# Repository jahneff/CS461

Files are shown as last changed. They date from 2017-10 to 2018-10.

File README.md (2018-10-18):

# Capstone-GS2 (Green Smart Gardening System)
Respository for Green Smart Gardening System Project

**This is a capstone project contracted by Intel and delivered by Jiayu Han, Brandon Ellis, and Jack Neff of Oregon State University. The finished product is a RESTful web app connected to an IOT environmental sensor array, designed to help farmers record and monitor environmental conditions on their land.**

Authors: Jiayu Han, Brandon Ellis, Jack Neff

Smart-Gardening-Capstone
This is the main repository for the 2017 capstone project: Green Smart Gardening System. Authors: Jack Neff, Brandon Ellis, Jiayu Han

The Green Smart Gardening System

Client: Po-Cheng Chen Affiliation: Intel

Motivation: 
The health of lawn and garden is strongly related to the environment factors (e.g. temperature, humility, and soil moisture). In order to have a better control and understanding on the environmental requirements for different plants, a smart garden system that can monitor, extract and control multiple environment parameters will help people reduce maintenance efforts and grow better plants more efficiently.

Description: 
Smart home gardening has become more popular these years. Throughout this project, students will develop a green energy powered Internet-of-Thing (IOT) device that monitors home environmental conditions by collecting real time crucial information under cloud database and further create an analytic model of the plants growing pattern. The Green Smart Gardening System will then interact with the existing smart house system (e.g. thermostat and sprinkler systems).

Objectives: 
Build a prototype of green energy (e.g. solar) powered IOT device focusing on the environmental condition monitoring. This project will enable students to learn how to interface with multiple sensors with a micro-controller and collect the analytic data through low-power wireless communication technology to the cloud data base.

Deliverables: 
A prototype of the smart gardening system with (1)	Basic environment monitoring capability (e.g. soil moisture, temperature, humility, and air condition, etc.) using green energy (2)	Transfer captured data into a computer for data analysis (3)	Transmit analyzed data into a phone or another device wirelessly (optional) (4)	Build data analytic model for plants health verse environment factors (optional)

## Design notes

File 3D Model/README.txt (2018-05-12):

This is the 3D model for packaging. 

The entire design was using Google Sketchup, and export as STL file for 3D printing.

Main, Mainlid:
	Most of sensors;
	MKR1000 with MKR stand;
	Breadboard.

MKR:
	MKR1000 stand.

SoilLeft, SoilRight:
	Soil Moisture sensor.

Solar, Solarlid:
	Solar panel;
	Battery;
	Light sensor.

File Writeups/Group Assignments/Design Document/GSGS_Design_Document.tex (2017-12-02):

\documentclass[IEEEtran,letterpaper,10pt,titlepage,fleqn,draftclsnofoot,onecolumn]{article}
%notitlepage vs titlepage
%fleqn left align

%\usepackage{nopageno} %no page numbers
\usepackage{indentfirst}
\usepackage{alltt}                                           
\usepackage{float}
\usepackage{color}
\usepackage{url}

\usepackage{graphicx}                                        
\usepackage{amssymb}                                         
\usepackage{amsmath}                                         
\usepackage{amsthm}                                          

\usepackage{balance}
%\usepackage[TABBOTCAP, tight]{subfigure}
\usepackage{enumitem}
\usepackage{pstricks, pst-node}
\usepackage{geometry}
\usepackage{hyperref}
\usepackage{textcomp}
\usepackage{listings}
%allows for code snipets

\geometry{textheight=9.5in, textwidth=7in} 

\newcommand{\cred}[1]{{\color{red}#1}} %think function call, changes text to red
\newcommand{\cblue}[1]{{\color{blue}#1}} %text to blue
\definecolor{dkgreen}{rgb}{0,0.6,0}
\definecolor{gray}{rgb}{0.5,0.5,0.5}
\definecolor{mauve}{rgb}{0.58,0,0.82}
\lstset{frame=tb,
  language=c,
  aboveskip=3mm,
  belowskip=3mm,
  showstringspaces=false,
  columns=flexible,
  basicstyle={\small\ttfamily},
  numbers=none,
  numberstyle=\tiny\color{gray},
  keywordstyle=\color{blue},
  commentstyle=\color{dkgreen},
  stringstyle=\color{mauve},
  breaklines=true,
  breakatwhitespace=true,
  tabsize=3
}

\def\name{Brandon Ellis, Jiayu Han, and Jack Neff}
\def\class{CS 461}
\def\assignment{Design Document}

%PDF Properties
\hypersetup{
  colorlinks = true,
  urlcolor = black,
  pdfauthor = {\name},
  pdfkeywords = {CS461 Senior Capstone Design Document},
  pdftitle = {\class \assignment},
  pdfsubject = {\class \assignment},
  pdfpagemode = UseNone
}

\begin{document}
%TitlePage
\begin{titlepage}
  \begin{center}
    \vspace{1cm}
    
    \huge
    \textbf{Green Smart Gardening System: Design Document}
    
    \vspace{1.5cm}
    
    \large
        \textbf{Brandon Ellis, Jiayu Han, and Jack Neff}
    
    \vspace{5cm}
    
    Abstract
    
    \normalsize
    This document discusses some core components that will make up our final product, a solar powered gardening device that provides the user with environmental data. There are three key pieces of functionality that this document will cover: Soil Moisture, Air Temperature \& Humidity, and Microcontrollers. The first two of these relate to environmental sensors that the chosen microcontroller will connect to. The last section covers the microcontroller itself. Each of these sections offer a description of the required task and go on to contrast different options to achieve these tasks.
    
    \vfill
    
    \large
        CS 461\\
        Fall Term\\
    \end{center}
\end{titlepage}

\section{Introduction}

This document will discuss core design aspects of our Green Smart Gardening System. It will detail nine different pieces of core functionality and note the member of our group assigned to it. The individual pieces will be discussed based on their hierarchy, which is shown in the section below. The pieces themselves are Soil Sensors, Air Sensors, Board Logic, Power, Wi-Fi, Database, Web Application, Displaying Data, and Packaging. 	These pieces will be discussed in terms of developing our device, a green energy powered garden monitoring system.

\section{Hierarchy}

\begin{figure}[H]
  \caption{Piece Hierarchy}
  \centering
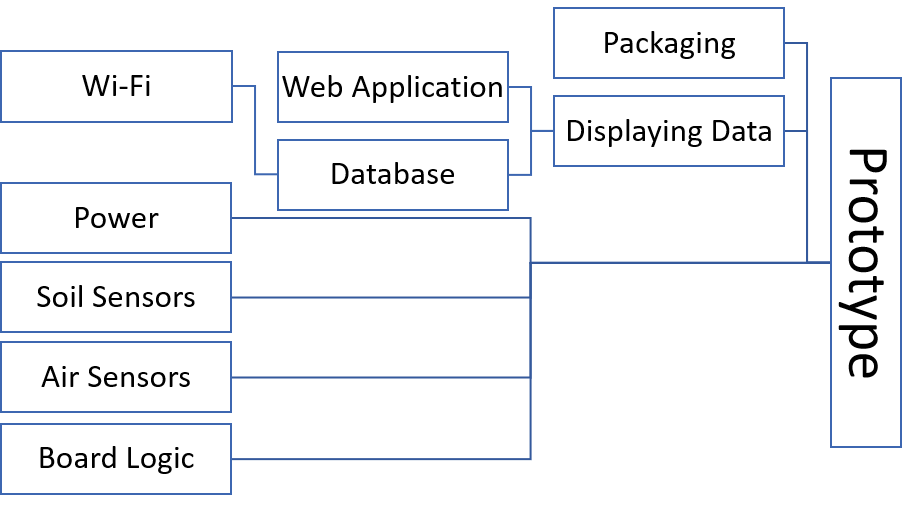
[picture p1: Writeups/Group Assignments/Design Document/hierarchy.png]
  
\end{figure}

\section{Design Pieces}
\subsection{Soil Sensors}
\subsubsection{Management: Brandon Ellis}

The first sensor related piece that will be covered is soil sensors. This section will cover two separate sensors, that together will achieve our devices soil requirements. These requirements being the measurement of soil moisture and soil pH. At this time, the two sensors that are being looked at to fill these roles are, respectively, the Phantom YoYo and the EZO pH Circuit. The process of integrating these sensors into our system will be the same for both. There will have to be a wired connection between each sensor and the board. There will need to be a software connection, so the board can easily communicate with the sensor. Finally, when this is all in place, the sensors will need to be tested.

\subsubsection{Hardware}

The first task in connecting the sensors to the board. For the YoYo, the required connections will be made through the sensor’s three pins: VCC, GND, and OUT. These three will support powering the YoYo and outputting measurements from it. Powering the sensor is fairly straightforward, with a wired connection simply needing to be made between the VCC and GND pins on the YoYo to their respective pins on the board. In order for the sensor to send information to the board, the last pin on the YoYo is used. The OUT pin is an analog output which can be connected to one of our board’s analog input pins. These three connections will be made through breadboard, in order to maximize the number of components our board can be interfaced with. 

\begin{figure}[H]
  \caption{YoYo Hookups}
  \centering
    \includegraphics[width=0.5\textwidth]
  {yoyo_hookup}
\end{figure}

For the EZO pH Circuit, there are some slight differences in connections. Power will still be handled in the same fashion as the YoYo, with the sensor’s VCC and GND connecting to the VCC and GND power pins of the microcontroller. The main difference between these two sensors is how output is handled. The EZO, instead of a single analog pin, uses two pins. These two pins are TX/SDA and RX/SCL. What this provides is two different connection modes, UART and I2C, working through these pins. Our board has options for both types, though I2C will most likely be used as it is more versatile when working with multiple components. The final hookup for the EZO is its replaceable sensor. This is the portion of the device that physically goes into the soil. It is connected through two pins on the EZO that link via a breadboard to the soil sensor’s screw-in connection point.
\begin{figure}[H]
  \caption{EZO Hookups}
  \centering
    \includegraphics[width=0.5\textwidth]
  {ezo_hookup}
\end{figure}

\subsubsection{Software}

Once the hardware connections to these two sensors have been made, the board needs to understand how to communicate with it. For the YoYo, using analog methods, this a simple matter of assigning the pin internally on the microcontroller and using the read command. The EZO on the other hand, because of its I2C communication mode, will require a little more work. In order to communicate with this sensor, the board will have to note its address and then perform reading operations on it in a slightly more expanded manner than using a single command. Sample code is provided for the EZO on exactly how to make this communication. 

\subsubsection{Testing}

When these two steps have been completed, a physical connection between the sensors and board has been made and data is able to be transferred to the microcontroller. When other pieces of our device have been implemented, specifically saving data to an SD card and wireless connectivity, testing can then be done. The actual testing of these sensors will be done through the Oregon State Greenhouses to compare against a reliable and accurate source. 

\subsection{Air Sensor}
\subsubsection{Management: Brandon Ellis}

The second large sensor piece that will be covered is air sensors. In order to fulfill the required functionality for our air sensor, we need to measure air temperature and humidity. The component chosen to fill this role is the SparkFun Atmospheric Sensor Breakout BME280. The BME280 not only measures both relative humidity and temperature, but also notes the barometric pressure. To integrate this sensor with our system there will need to be a wired connection between the device. This will then allow communication from the sensor to our board, which will in turn allow us to test the validity of our data.

\subsubsection{Hardware}

The first step in this process is the physical connection of the BME280 to our board. In order to connect the two, the sensor requires power and a method of communication. To facilitate power, the BME280 has two pins that will need to be wired to the board. These are VCC and GND, to respectively provide 3.3V of power and a ground line. When these have been connected, there are then two forms of communication that the BME280 can utilize. In the above section, the EZO pH Circuit had two communication methods sent over the same pins. The BME280 differs by having two completely separate buses that each have their own method of communication, I2C and SPI. Though, like the EZO, the method of communication that we will be using is I2C, as it is the best method when working with multiple components connecting to a board. Connecting through I2C will entail connecting two pins, SDA and SCL, to their respective pins on our microcontroller.

\begin{figure}[H]
  \caption{BME280 Hookups}
  \centering
    \includegraphics[width=0.5\textwidth]
  {bme280_hookup}
\end{figure}

\subsubsection{Software}

When first step is complete, a hardware connection has been created to our sensor. The microcontroller then needs to have software created to communicate with the sensor and retrieve data from it. Because of the method of communication being through I2C, the implementation of software for the BME280 will require noting the I2C address and dictating operations for the sensor. To do this, the BME280 provides several pieces of sample code and example configurations.

\subsubsection{Testing}

Finally, when the hardware and software connections have been created data can be outputted from the sensor to the board. At this time, assuming that functionality is in place to further output data wirelessly or to a SD card, testing can begin. Like the above soil sensors, testing will be done with the Oregon State Greenhouses in order to test the accuracy of our data points against theirs. 

\subsection{Power}
\subsubsection{Management: Jiayu Han}

For the power source section, there are some criteria we need to follow. First, Green Smart Gardening System needs to use renewable energy as the primary power source, it is supposed to use solar power as much as possible. Second, the device is supposed to run without any solar power for an entire week since Oregon rains so often during November to March. It will be hard to fully rely on the solar power during the wet season in Oregon. 

To reach the first criterion, the device needs to be powered by the solar power for most of the time. The micro-controller, Arduino MKR1000, has a great feature to achieve it. According to Arduino website [1], MKR1000 has two battery connectors, the USB power source and the Vin. The USB power source will be disconnected if there is appropriate power detected through Vin. The board has a 5V power supply voltage and a 3.3V operating voltage. By plugging the 5V solar panel through the Vin and the 3.7V Li-ION batteries through the USB, the board will always use the solar panel as the power source when it is available.  Based on the reviews on SparkFun [2], the solar panel will become undetectable once the voltage drops below 3.3V, and the Li-ION batteries will kick in from that.

\begin{figure}[H]
  \caption{MKR1000 Power[3]}
  \centering
    \includegraphics[width=0.5\textwidth]
  {power_graphic_1}
\end{figure}

As a backup plan for the power source, the solar module for Arduino [5] is also a great solution. It combines the solar panel and rechargeable batteries into one power source for the Arduino board. The module can handle two different inputs. The 3.7V to 7.0V one will be able to charge the battery, and the 3.7V to 6.0V one will be able to carry out the charge from the USB. Both solar panel and batteries are easy to change to the specific ones fit the device.

\begin{figure}[H]
  \caption{Solar Module[5]}
  \centering
    \includegraphics[width=0.5\textwidth]
  {power_graphic_2}
\end{figure}

To achieve the second criterion, the battery capacity needs to be at least 34000mAh. According to Arduino, the Wi-Fi module on MKR1000 absorbs roughly 100mA when connected to Wi-Fi with data transferring. The board consumption without Wi-Fi module initialized is 20mA. Based on the specs from the Technology Review document for the project, the preferred air temperature and humidity sensor and soil moisture sensor have a total of 21mA. Based on the equation from Arduino website, Battery Life = (Battery Capacity)/ (Maximum Current Consumption) * 0.7, we can get the equation for battery capacity, Battery Capacity = (Battery Life) *(Maximum Current Consumption)/0.7, which the battery capacity = (7*24h) * (141mA)/ 0.7 = 33840mAh.

\subsection{Wi-Fi}
\subsubsection{Management: Jiayu Han}

One of the biggest benefits of choosing Arduino MKR1000 as the micro-controller is that it comes with the ATSAMW25 Wi-Fi module on board, which makes it the ideal solution for designing IoT project. The on-board Wi-Fi module has up to 72Mbps with a great operating temperature range from -40°C to +85°C.

In order to get the Arduino MKR1000 connected to Wi-Fi, you will only need the MKR1000 with Arduino IDE. Before connecting the MKR1000 with the Wi-Fi, the MKR1000 needs to be already set up to connect to computer and able to upload custom sketch. After the MKR1000 is successfully connected, we will go to the Arduino WIFI 101 Shield repository on GitHub[6] to aquire the zipped Wi-Fi library. Then, we will open the Arduino IDE, find the “Include Library” in Sketch menu, and click “Add .ZIP Library” to add the repository. After these three steps, the MKR1000 is ready to connect to the Wi-Fi. We will need to include the WiFi101 library in the sketch and pick the Wi-Fi which it needs to connect to. 

\subsection{Board Logic}
\subsubsection{Management: Brandon Ellis}

Board logic handles the overarching software that will control and coordinate our device. While each of the sensors will have its own software associated with it, the purpose behind those pieces is heavily focused on communication and data retrieval. This section will detail some of the broad functionality that will be created as well as their associated testing.

The main pieces of functionality that will be discussed are data retrieval, outputting data, and scheduling. Out of these three, data retrieval is going to play the most off the software developed for each sensor. This piece of functionality will be responsible for querying those implemented functions and returning with the data. Once data has been retrieved, the data outputting portion will take over handling it. Retrieved data will be formatted and stored on an SD card. This will serve as a way to first back up the data. As our device is run off solar power and a battery, in the event of poor weather conditions for an extended period we need to be able to save the data in case transmitting would cause too much of a power draw. This way, when data is outputted it will be collected from the SD card to ensure it is backed up prior to transmission. The final piece of functionality that will be added is scheduling. Scheduling is the automated nature of our device to ensure that readings are taken in standard intervals. This addition will control when readings are taken from each sensor and when data this data will be transferred.  

Finally, this leaves how these pieces of functionality will be tested. There will be two main types of testing done on this software. The first will cover data retrieval and output, which is through unit testing. This will simply ensure that each of these individual pieces are operating correctly. The other type of testing that will be conducted is integration testing. This will be used to validate the scheduling portion, specifically this style of testing will aid in making sure that all of the individual pieces are able to work in tandem within our system.

\subsection{Database}
\subsubsection{Management: Jack Neff}

The storage and access of data is one of the most important aspects of our project, which is very data driven. Without the ability to consistently gather and store data, our application would be useless. This begs the question as to what database should we use, and what storage engine within that database? 

Database availability was the chief factor here. Each platform has a database software associated with it, so by selecting a platform one effectively is restricted to that platform’s database. We reasoned that users wouldn’t have much to do with the database. In fact, the less they have to do with it, the better. Therefore we picked our database solely based on our own needs and whether it met them. MySQL is one the three of us are all familiar with, and since it is supported by Google Cloud, we opted to go with it. [7]

We have more choices for the database storage engine. Our database has few outstanding requirements. Speed is not our top concern. Although we want to make sure our application is never sluggish, the nature of our application would allow us to voluntarily reduce data throughput in case of a slowdown, with minimal performance impact. For example, if we queried the database to graph environment data for a full year, we could leave out every other data point to reduce the workload by half, and still end up with a similar graph, provided our measurement interval is short enough. Additionally, In order to implement our preferred structure, foreign key support will be required, for cross-table references, as well as transaction support for data simplification possibly the computation of metrics. This led us to select InnoDB as our storage engine, because it supports foreign keys and transactions, is very fast, and we have all used it before. Also, InnoDB supports multi-view concurrency control (MVCC), which means we can all work on the database at the same time with no issues.[8]

A final design consideration regarding the database is what should be stored, and in what form? Our data will consist mostly of environmental measurements associated with a timestamp. For example, one database column could be Temp and another could be Time. This would allow us to graph the temperature over time. To simplify data analysis and display, we will design the input to come through in “packets.” We are measuring a lot of environmental factors (temperature, humidity, soil moisture, etc.), and if they each had their own timestamp, things would get very messy. Therefore, we want these packets to hold one measurement of each environmental variable, coupled with a timestamp that corresponds to all those measurements. These packets will be easily graphed and will be highly comparable because of their common timestamps, which will make generating views easier.

\subsection{Web Application}
\subsubsection{Management: Jack Neff}

Server stack implementation is an important software design decision for us. We refer to this design aspect as the server platform. The question is, what platform should we select to store and maintain our application and all its data? Users will be dependent on this platform to support their data needs, and to form the operational infrastructure of the Gardening System. Primarily we want to direct this design based on scalability and reliability, with a secondary concern for ease of use by the user. 

One design decision involving the server stack is what operating system we want it to be usable on. Several popular server platform stacks such as WAMP are windows only, while others are specifically designed for Linux, and still others work with any OS. In the interest of reaching the largest possibly client base, we wanted to use a server stack that was supported on all operating systems. This is one of the design points that led us to select Google Cloud Platform as our web server: it isn’t platform specific.

Another factor is scalability. As a group we have experience of hosting http servers on a local virtual machine, only to have performance suffer when data operation and data storage volumes became too large for it to handle. The Google Cloud Platform is supported on hearty and fast infrastructure, the same which supports google searches, or playback of YouTube videos. It is a tried and true resource capable of handling lots of computing, which we may need if we ever adapt our design full scale. Our prototype will be a small system consisting of one of a few plants, but the large scale implementation of a vineyard or orchard (or multiple) would significantly increase data throughput and calculations done in analysis. 

One fairly obvious design choice was what language to use to implement the web application. The language needs to be able to interface between database and web browser, and should preferable be simple, and a language we the developers are already familiar with. We selected PHP because it is supported by all server platforms, and is known for being one of the easiest if not the easiest language for accessing databases. It also helps that all three of us have experience programming in PHP, and querying databases in PHP. 

Other, lesser factors included reliability and ease of use by the developers. Reliability is not an emphasis here simply because most server platform stacks are pretty reliable. Google Cloud Platform though, especially, is known to be very reliable, since it is based on Google’s famous infrastructure. Ease of use was a concern entirely our own, and is important because selecting an easy-to-use application saves time and effort that could have been spent debugging or learning to use the software. Known for being easy to use and for having a large body of community support online, the Cloud Platform satisfies this requirement well. 

\subsection{Displaying Data}
\subsubsection{Management: Jack Neff}

Data display is the key to bringing information to the user in a way that is easy to understand and can inform their agricultural decisions. Data displays should be easy to understand, and be viewable on the web-based user interface. Users should be able to easily construct their own graphs based on available data. In addition, some graphs should be automatically generated from data in the database. This part of our design is completely geared toward the user. We want to make the data we collect very understandable, even by someone without a lot of math, computer, or agricultural experience. Also, we want to give the user relevant information, rather than just bombarding them with numbers and timestamps. Finally, we want the data to look good, and dynamically create graphs and views without causing any slowdown.

To fulfill cosmetic requirements, we selected D3js as our API for data display. This is a JavaScript library that provides lots interesting data display functionality. In addition, because it is a JavaScript library and not a program itself, we expect it will be fast and lightweight. [9]

When the user logs into the web application, they should have the most valuable information distilled for them on the main page. Although at first in our design we flirted with trying to implement low-level machine learning, we have now realized there won’t be enough time, so we will be doing independent research into plant growth to find out what types of plants are healthy in what environments. Using these known benchmarks, we will provide users with information about their system’s environment, and how this information relates to the ideal environment conditions for a plant. An early design idea is to have a colored bar or a circle for each environmental variable plainly visible on the application front page. If the variable is within acceptable bounds, the graph element would be green, and red if not. By clicking on that element, a user could view a graph of that element by itself over time, and analyze why it is out of the required range.

One interesting design consideration is how much freedom to allow the user to have when graphing their own data. Because users of this product may not be very computer-savvy, the users’ ability to make their own graphs should be limited to a few preset options, to avoid presenting them with an overwhelming array of choices. Variables should be graphable against one another, as well as against time, and there should be a wide number of graphical options for each type of graph. D3js specializes in radial displays and maps, and since we won’t be needing maps, we will likely design a number of radial displays. Users should be able to save their graphs and mount them on the front page of the web app if they like. 

One of the keys to an enjoyable user experience is speed and responsiveness of an app. We want the user to see graphs as soon as they log in, but if these dynamic graphs hurt performance, that is unacceptable. We will implement some kind of contingency against this, so instance, if the application detects that the front page of the app is loading slowly, it should cut the number of data points in half by selecting every other one, and then reload the page. User experience needs to be the absolute focus of this design element. There is no utility in showing off data or graphs unless the user wants to view them and is not put off by long loading times.

\subsection{Packaging}
\subsubsection{Management: Jiayu Han}

Our vision of the device will be stored in a package. The micro-controller and the batteries along with most of the cables will be stored inside of the case in order to protect them from damaging. Outside of the package will only have the solar panel, the soil moisture sensor and the air temperature \& humidity sensor to collect the energy to power up the device and the data for analyzation. In order to make the device package firm with high pressure resistance, cylindrical package will be the best option. It will easily hold its shape to protect the device inside from sticking into the soil. The solar panel will be set at the top of the package so that it could produce solar power at its maximum efficient. The air temperature \& humidity sensor will extend from the top of the side so that the temperature and humidity will have a lower chance of appearing errors because of the ground temperature and humidity. The soil moisture sensor will come out from the bottom of the package in order to get to the similar depth as the root of the plants to collect more precise data.

Based on the purpose of the Green Smart Gardening System, the device needs to be used outdoor and waterproof. Since the Green Smart Gardening System is meant to be an IoT device, we need to avoid any metal case to ensure that we can get the best Wi-Fi connection. Because the device is meant to work outdoor in Oregon, where has a long wet-season, we need to keep the package fully sealed up to prevent the water and other stuffs in the soil from corroding and short circuit. Since the temperature in Oregon could range from -10°C to 40°C+ during the year, the material of the case need to sustain both low and high temperature. The lunch box like plastic material could be a great choice. 

\clearpage

\section{References}
[1] "Arduino MKR1000 WIFI", Arduino, 2017. [Online]. Available: https://store.arduino.cc/usa/arduino-mkr1000. [Accessed: 30- Nov- 2017].

\vspace{1mm}

[2]"Arduino MKR1000 (with Headers) - DEV-14393 - SparkFun Electronics", Sparkfun.com, 2017. [Online]. Available: https://www.sparkfun.com/products/14393. [Accessed: 30- Nov- 2017].

\vspace{1mm}

[3]Arduino, Arduino MKR1000 WIFI. 2017.

\vspace{1mm}

[4]"Solar Module for Arduino", Cooking-hacks.com, 2017. [Online]. Available: https://www.cooking-hacks.com/documentation/tutorials/arduino-solar/. [Accessed: 30- Nov- 2017].

\vspace{1mm}

[5]Cooking Hacks, Solar Powered Arduino. 2017.

\vspace{1mm}

[6]"arduino-libraries/WiFi101", GitHub, 2017. [Online]. Available: https://github.com/arduino-libraries/WiFi101. [Accessed: 30- Nov- 2017].

\vspace{1mm}

[7]S. Hull, "MySQL face-off: MySQL or MariaDB?", InfoWorld, 2017. [Online]. Available: https://www.infoworld.com/article/2611812/mysql/mysql-face-off--mysql-or-mariadb-.html. [Accessed: 30- Nov- 2017].

\vspace{1mm}

[8]"MySQL :: MySQL NDB Cluster 7.5 :: 3.5.1 Differences Between the NDB and InnoDB Storage Engines", Dev.mysql.com, 2017. [Online]. Available: https://dev.mysql.com/doc/mysql-cluster-excerpt/5.7/en/mysql-cluster-ndb-innodb-engines.html. [Accessed: 30- Nov- 2017].

\vspace{1mm}

[9]M. Bostock, "D3.js - Data-Driven Documents", D3js.org, 2017. [Online]. Available: https://d3js.org. [Accessed: 30- Nov- 2017].

\end{document}

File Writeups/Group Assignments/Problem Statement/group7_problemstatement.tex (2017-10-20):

\documentclass[IEEEtran,letterpaper,10pt,titlepage,fleqn,draftclsnofoot,onecolumn]{article}
%notitlepage vs titlepage
%fleqn left align

%\usepackage{nopageno} %no page numbers
\usepackage{indentfirst}
\usepackage{alltt}                                           
\usepackage{float}
\usepackage{color}
\usepackage{url}

\usepackage{graphicx}                                        
\usepackage{amssymb}                                         
\usepackage{amsmath}                                         
\usepackage{amsthm}                                          

\usepackage{balance}
%\usepackage[TABBOTCAP, tight]{subfigure}
\usepackage{enumitem}
\usepackage{pstricks, pst-node}
\usepackage{geometry}
\usepackage{hyperref}
\usepackage{textcomp}
\usepackage{listings}
%allows for code snipets

\geometry{textheight=9.5in, textwidth=7in} 

\newcommand{\cred}[1]{{\color{red}#1}} %think function call, changes text to red
\newcommand{\cblue}[1]{{\color{blue}#1}} %text to blue
\definecolor{dkgreen}{rgb}{0,0.6,0}
\definecolor{gray}{rgb}{0.5,0.5,0.5}
\definecolor{mauve}{rgb}{0.58,0,0.82}
\lstset{frame=tb,
  language=c,
  aboveskip=3mm,
  belowskip=3mm,
  showstringspaces=false,
  columns=flexible,
  basicstyle={\small\ttfamily},
  numbers=none,
  numberstyle=\tiny\color{gray},
  keywordstyle=\color{blue},
  commentstyle=\color{dkgreen},
  stringstyle=\color{mauve},
  breaklines=true,
  breakatwhitespace=true,
  tabsize=3
}

\def\name{Brandon Ellis, Jiayu Han, and Jack Neff}
\def\class{CS 461 }
\def\assignment{Problem Statement}

%PDF Properties
\hypersetup{
  colorlinks = true,
  urlcolor = black,
  pdfauthor = {\name},
  pdfkeywords = {cs461 ``Senior Capstone' Problem Statement},
  pdftitle = {\class \assignment},
  pdfsubject = {\class \assignment},
  pdfpagemode = UseNone
}

\begin{document}
%TitlePage
\begin{titlepage}
	\begin{center}
		\vspace*{1cm}
		
		\huge
		\textbf{Green Smart Gardening System: Problem Statement}
        
        \vspace{1.5cm}
        
		\large
        \textbf{Brandon Ellis, Jiayu Han, and Jack Neff}
		
		\vspace{5cm}
		
		\normalsize
		This paper covers the challenges and solutions proposed in Green Smart Gardening System, an analytical smart gardening device. First, this paper will address the problem that our created device will seek to solve. It will then discuss the proposed solution, broken down into the device’s inputs, outputs, hardware, and analysis. Finally, this paper will conclude with some estimated performance metrics which will define the completion of our device.
		
		\vfill
        
		\large
        CS 461\\
        Fall Term\\
    \end{center}
\end{titlepage}

\section{Description of Problem}

As the use of smart home technology increases so has the interest in smart gardening. We plan to create a device that can simplify some aspects of gardening and provide the user with more in-depth analysis of their garden. The device would enable the user to contrast the health of their plant with environmental statistics, making informed care of their garden that much easier. The original use case for this device was based around the wine industry in Southern Oregon. The creation of a smart gardening device, specifically in this growing sector, would aid in the growth of both businesses and the plants that sustain them. 

\vspace{5mm}

Digital gardening systems are nothing new. Timed irrigation, lighting, and humidity systems are commonplace today, but they are heavily reliant on user input, and are not capable of monitoring plant growth or health. If an inexperienced user sets the timers wrong, or fails to account for a change in environmental factors, this type of automated gardening system will fail. In our design, we want to build something that an inexperienced user will be comfortable using, and that will provide gardeners and farmers with a better understanding of important factors in the growth process. If plants are wilting or dying, at the very least our system will alert the user, prompting them to change the settings. Ideally, we will be able to design a system that self-corrects, totally minimizing the responsibility of the user. As it grows plants, our system will report environmental factors, water use, and plant growth and provide the user with data and graphics relating these factors, to give them a better understanding of their garden. This will involve devising a way to measure plant growth, and writing algorithms that analyze and plot relevant data.

\vspace{5mm}

When we shift responsibility from the user to the system, we need to find a reliable and efficient way to power that system. As far as efficiency goes, this means calculating the energy requirements of our proposed system, and finding an appropriate battery that isn’t unnecessarily large or expensive. For redundancy, we will also install solar panels to power the array on nice days. Solar panels will be spotty for a certain period of time in the colder months, so we will need to select a battery that lasts longer than that period. 

\vspace{5mm}

\section{Proposed Solution}

What this project is aiming to accomplish is the creation of an environmental monitoring device. While a specific microcontroller has yet to be narrowed down, said device has a number of specific necessities. I will be breaking these specifics down into four portions: input, output, hardware, and analytics.

\subsection{Input}

To fulfill the gardening aspect of this device, it tracks several environmental conditions. For soil, the device will measure the moisture level in the soil as well as the ph. Additionally, a single hardware addition will capture the ambient air temperature, the air humidity, and air pressure. There is also the possibility of adding the control or information from an automated watering system to the devices network.

\subsection{Output}

Once all of the above inputs have been recorded, the device needs to send them somewhere useful. There is one location planned currently for the data to go, but there are several routes that the data can take from it. First the data will always go to a computer for analysis. Once the data has been quantified, a couple different things could occur depending on our group’s initial and stretch goals. The first is that the data could be sent wirelessly to a smartphone or another smart device. From there, the user could reference a more viewable representation of the data at their leisure. The second tags onto outputting the data for viewing, a current stretch goal is the creation of a viewing model that would compare specifics plants’ health against noted environmental factors. Lastly, the computer would be able to interface with an existing smart home system to control environmental factors. These could include the ambient temperature, lighting, and sprinklers.

\clearpage

\subsection{Hardware}

To achieve this the microcontroller will have to be augmented. First, the inputs require the device communicates with several sensors. Specifically, we are currently looking at the Adafruit BME280 I2C, for soil temperature, humidity, and pressure; DFRobot Gravity, for soil moisture; and EZO pH Circuit, for the pH of the soil.

\vspace{5mm}

Once the data has been collected, the microcontroller needs to output it. Depending on the direction of the project, the output could be done a couple of different ways. There will be a guaranteed connection from the device to a computer for the analysis of data. This will most likely be achieved by a wireless connection between the two, though it could be hardwired. When the data has been analyzed by the computer, there is a stretch goal that would connect said computer wirelessly to a smartphone or other internet enabled device. All of these result in the microcontroller needing at least one possible form of wireless output.

\vspace{5mm}

The last hardware requirement lies in how the device is powered. A key requirement is that the microcontroller be powered through green methods, with the preferred form being solar. This will mean that the device will need to have a solar panel that into the microcontroller. The current battery pack being eyed is the MSP430. To fulfil all requirements this charger may need to be expanded, as it has the possibility to add additional solar panels. It does have a rechargeable battery contained within for storing the charge during lower light.

\subsection{Analytics}

This bring us to the last piece of functionality, the analysis of data. There are two separate portions to this. The first analysis is done purely on the recorded data. After the microcontroller outputs raw data to a computer, an analytical model is required to be viewable. This model provide access all of outputted data. It does not contrast this information, instead simply making it accessible for the user to reference. The second form of analysis is currently a stretch goal. This analysis is on the aforementioned data once it has been outputted to the computer, but it does contrast the information against the general health and growth of a specific plant. At this point, how the health and growth are measured is undefined. Most likely these values will be inputted by the user, based on their insights and measurements. If we are able, we could use a common data mining algorithm like SVM or k-means to figure out what environmental configurations help or harm a plant, and what configurations produce the most growth. 

\vspace{5mm}

\section{Performance Metrics}

For this project to be considered complete, there are several criteria. First, the microcontroller must receive valid, continuous within the realm of the input’s rate, string of data from each of its inputs. This will result in the device collecting data, in designated intervals, on the soil, temperature, and air. Second, the microcontroller must be powered through solar energy. This will result in a green device, which is a key requirement for this project. Third, all captured data must be fed to a computer, and said computer must quantify all data for the user’s viewing. When these three tasks have been completed, the base specification of the device will be achieved. However there is one key aspect of this device that is overarching. This is the assurance that the microcontroller and all of its additions can continue to perform under varying climates. Specifically, the original use case that was mentioned above, was for the creation of a device to aid the wine industry in Southern Oregon. Such a device would have to monitor all of aforementioned environmental aspects, as well as work in anything from sun to snow to rain.

\vspace{5mm}

To reach the full stretch goals for the project two more requirements must be met. The first is that once the data has reached the computer for analysis, it can be transmitted wirelessly for viewing on another device. The second stretch goal is the creation of an analytical model for comparing the health of a plant with the data received from the microcontroller. The health of the plant will, at this time, be defined by the user. This information would be viewed at either the main computer or sent wirelessly to a device. 

\end{document}

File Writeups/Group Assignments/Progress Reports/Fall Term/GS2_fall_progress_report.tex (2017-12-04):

\documentclass[IEEEtran,letterpaper,10pt,titlepage,fleqn,draftclsnofoot,onecolumn]{article}
%notitlepage vs titlepage
%fleqn left align

%\usepackage{nopageno} %no page numbers
\usepackage{indentfirst}
\usepackage{alltt}                                           
\usepackage{float}
\usepackage{color}
\usepackage{url}

\usepackage{graphicx}                                        
\usepackage{amssymb}                                         
\usepackage{amsmath}                                         
\usepackage{amsthm}                                          

\usepackage{balance}
%\usepackage[TABBOTCAP, tight]{subfigure}
\usepackage{enumitem}
\usepackage{pstricks, pst-node}
\usepackage{geometry}
\usepackage{hyperref}
\usepackage{textcomp}
\usepackage{listings}
%allows for code snipets

\geometry{textheight=9.5in, textwidth=7in} 

\newcommand{\cred}[1]{{\color{red}#1}} %think function call, changes text to red
\newcommand{\cblue}[1]{{\color{blue}#1}} %text to blue
\definecolor{dkgreen}{rgb}{0,0.6,0}
\definecolor{gray}{rgb}{0.5,0.5,0.5}
\definecolor{mauve}{rgb}{0.58,0,0.82}
\lstset{frame=tb,
  language=c,
  aboveskip=3mm,
  belowskip=3mm,
  showstringspaces=false,
  columns=flexible,
  basicstyle={\small\ttfamily},
  numbers=none,
  numberstyle=\tiny\color{gray},
  keywordstyle=\color{blue},
  commentstyle=\color{dkgreen},
  stringstyle=\color{mauve},
  breaklines=true,
  breakatwhitespace=true,
  tabsize=3
}

\def\name{Brandon Ellis, Jiayu Han, and Jack Neff}
\def\class{CS 461}
\def\assignment{Fall Progress Report}

%PDF Properties
\hypersetup{
  colorlinks = true,
  urlcolor = black,
  pdfauthor = {\name},
  pdfkeywords = {CS461 Senior Capstone Fall Progress Report},
  pdftitle = {\class \assignment},
  pdfsubject = {\class \assignment},
  pdfpagemode = UseNone
}

\begin{document}
%TitlePage
\begin{titlepage}
  \begin{center}
    \vspace{1cm}
    
    \huge
    \textbf{Green Smart Gardening System: Fall Progress Report}
    
    \vspace{1.5cm}
    
    \large
        \textbf{Brandon Ellis, Jiayu Han, and Jack Neff}
    
    \vspace{5cm}
    
    Abstract
    
    \normalsize
    The purpose of this document is to detail the progress that Green Smart Gardening System has made for the fall term. It will cover a brief overview of our project, where we are in our device, problems found, and a retrospective on the work we accomplished by week.
    
    \vfill
    
    \large
        CS 461\\
        Fall Term\\
    \end{center}
\end{titlepage}

\section{Our Project}

The Green Smart Gardening System (GS2) is designed to monitor an array of plants and provide the user with relevant environmental information so they can more effectively tend to their plants. It is specifically designed to operate very autonomously, automatically measuring and graphing data as well as drawing power from a solar panel in conjunction with a replaceable battery. The end goal is to produce a microcontroller/sensor/solar panel platform that can monitor an array of plants (say, in a vineyard) and relay the data to a database accessible from a web browser, or possibly a smartphone and tablet app. 

\subsection{What It Is}

The GS2 is an automated smart gardening system. At a high level, it is a device that monitors the environmental factors in a garden and transmits them to where a user can view them. It will not control watering dosage or any other environmental factors. It will only measure them and leave the responsibility of acting on data to the user. When data is viewed, it will be assessed by the system to be a healthy or unhealthy measurement, and indicate to the user what measurement(s) are not at ideal levels. These ideal levels will be determined by research.

\subsection{What It Does}

The GS2 needs several steps to map environmental data to user-oriented views. A sensor array is connected to the microcontroller via cables, and uses I2C protocol to transmit data. The microcontroller will send the raw data via Wifi to a database hosted on Google Cloud. From there, the data will be sanitized into legible numbers, and then packaged together so that each packet will have one measurement from each sensor. These packets will be stored in the database in their own table, with a timestamp in each packet. A combination of PHP and JavaScript will allow us to display the data on a web browser for the user.

\subsection{Who It Is For}

Our clients originally described the system as “one you might find in a vineyard.” So far, we have designed everything with this application in mind. Other applications would include orchards, floral farms, and vegetable gardens. The solar panel/battery combination will be originally calibrated to local Willamette Valley weather, so this system will be most suited to local farmers. 

\section{Goals}

The goal is to design a system that is easy to set up, accurate, and presents data in easily understood ways in real time and over periods of time. It will center around a microcontroller that has internet capability, solar panel power supply with backup battery, and continuously read in relevant data from sensors we have set up. I would say that one of our most important goals to reach is presenting data to the user in the most lightweight, interesting, and relevant possible. We don’t want to provide any clunk or convoluted visuals. Also being able to read consistent and accurate data with the sensors, and have them operate together in relative unison, will be an important goal. Possibly the toughest challenge will be getting all the component parts to communicate with one another in a meaningful way. The data gathered by sensors needs to be sanitized and relayed between systems in order to reach the user in the form of a graph or other visual. Once we reach this goal, we will know we are on the right track.

\section{Where We Are}

At the moment, we have just completed the design phase. We have selected all our sensors, our microcontroller, out battery, solar panel, database, and server platform. Several microcontrollers and sensors have already been ordered, along with breadboards. Over the next few weeks we plan to familiarize ourselves with the microcontroller and sensors, and test them to the best of our abilities. We plan to test in one of the greenhouses on campus, because they have temperature and humidity gauges we can compare our own data to. While we mess around with these components, we will also be familiarizing ourselves with the Google Cloud Platform, where our database and front-end application will be stored. By the time the next semester starts, we expect to be able to accurately read raw data with our sensors and translate it into legible numbers. Also we expect to have a functioning database and low-level PHP/JQuery-based views of the placeholder data within. 

\section{Problems Impeding Progress}

So far, problems have been minimal. Finding reliable sensors is one of the more persistent ones, and won’t be resolved until we have tested and verified all the sensors we will use. Many of the sensors available online have mixed reviews, so we will need to personally test all our sensors for accuracy. Another problem we ran into was our initial preferred microcontroller was discontinued a short time ago, and was the only microcontroller that suited all of our functionality needs while also providing a Bluetooth module. We found a nice replacement, but it lacks Bluetooth, which we had thought about implementing as a stretch goal, for use when the user is away from their computer and instead is near the system itself. 

\section{Retrospective of Past 10 Weeks}

Note: With the amount of information that our group wanted to cover for this section, we elected not to display it in the format of a grid. Instead we have our retrospective broken down by week with each instance covering any activities, problems, and solutions that came up that week.

\subsection{Week 1}
\subsubsection{Activities}

This is before we were in a group together. We submitted our project preferences this week.

\subsubsection{Problems}

N/A

\subsubsection{Solutions}

N/A

\subsection{Week 2}
\subsubsection{Activities}

We were assigned our project this week. The three of us met together to introduce ourselves and talk about our vision for the project. We then contacted our  clients and decided to set up a weekly meeting. After discussing what we thought the product would end up like, we began to write our individual problem statements. 

\subsubsection{Problems}

None

\subsubsection{Solutions}

None

\subsection{Week 3}
\subsubsection{Activities}

We met with our TA, Daniel Lin, for the first time. He recommended not being shy when contacting clients. We met with our clients on Thursday, which became our weekly meeting slot. We used the Skype Business app. The clients outlined their vision for the project to us, and we shared our Github repo with them. We also completed our problem statements. 

\subsubsection{Problems}

Jack had a time conflict and couldn’t make the TA meeting. 

\subsubsection{Solutions}

Brandon began to communicate the topics of the meeting to Jack afterwards, so he could stay updated.

\subsection{Week 4}
\subsubsection{Activities}

This week we began our preliminary research, looking online for microcontrollers, sensors, and smart gardening setups implemented by others in the past.We also looked into available microcontrollers, especially at their power consumption. We put together our group problem statement. This is the week our clients shared a Google Drive presentation with us to store meeting notes and design ideas. This became a very important resource in later weeks. 

\subsubsection{Problems}

None

\subsubsection{Solutions}

None

\subsection{Week 5}
\subsubsection{Activities}

We settled on all the environmental variables we wanted to measure, and then did online research to make sure that it was possible to find compatible sensors to measure all of them. We discussed this research with our TA and clients, and began work on the Requirements document. The TA advised us on the writing of the requirements document, and our clients tasked us with researching the components deeper the following week.

\subsubsection{Problems}

Many sensors that looked promising initially operate at different voltages. Some sensors are 5.0V, some are 3.3V, and some microcontrollers can handle one of the two, some both. 

\subsubsection{Solutions}

We decided to assume both cases, so we made component lists for a 3.3V setup and a 5.0V setup. The lists were mostly the same, but a few of the sensors were different. We would decide which to use after selecting our microcontroller. 

\subsection{Week 6}
\subsubsection{Activities}

Our group confirmed our preliminary selections of sensor and microcontroller parts, and created a block diagram to show how the system would all be connected. We decided to go with a 3.3V system, because the components in that version of our setup seemed to be more reliable, based on the online reviews. Also, they all were supportive of I2C, a low-level communication protocol. We started getting more into the research of the solar panel, and began writing our tech reviews. In the weekly meeting, our clients requested we finalize our component list so that they could order the parts. Finally we completed and submitted our group requirements document. 

\subsubsection{Problems}

No problems that had to be solved this week, but after selecting some components and creating a block diagram, a few future problems we would need to solve became clear. For one, we are going to face one of our largest challenges transferring raw data from these low-level sensors to this intermediary microcontroller, and then outputted over WiFi high-level database.

\subsubsection{Solutions}

We plan to use I2C to connect the sensors to the controller. We then need to connect the controller to WiFi. Depending on the microcontroller we choose, we may or may not need to purchase an additional WiFi module. Over the WiFi we need to send data, probably using UDP, to our web server and accompanying database. 

\subsection{Week 7}
\subsubsection{Activities}

In week 7, we finished our requirements document, and partially completed our final component list. We selected all the sensors, and the solar panel. The only thing left is the microcontroller and battery, which we discussed with our clients in the weekly meeting. We divided the project up for the technology review. This division will likely continue throughout the project. Brandon is in charge of the sensors and the microcontroller, Jiayu is in charge of the microcontroller power supply, the solar panel, and the physical design of the system. Jack is handling the database, UI, and web server implementation. 

\subsubsection{Problems}

We learned that our first choice for microcontroller, the Arduino 101, is no longer in production. Although they’re still available for purchase, there is no point in building a system with an obsolete piece of tech as the centerpiece. 

\subsubsection{Solutions}

One of our clients offered his personal opinion for the microcontroller we should select, the MKR1000. We are going to research it next week. 

\subsection{Week 8}
\subsubsection{Activities}

We finished our individual tech reviews. Also had our testing approved by the OSU Greenhouse. We discussed our chosen microcontrollers, finalized component list, and options for the web server with clients. They recommend we check the capstone lab and see if they have any of the microcontrollers or other components we need. 

\subsubsection{Problems}

None

\subsubsection{Solutions}

None

\subsection{Week 9}
\subsubsection{Activities}

Just research and Thanksgiving this week. 

\subsubsection{Problems}

Too Much Turkey

\subsubsection{Solutions}

Eat The Turkey

\subsection{Week 10}
\subsubsection{Activities}

Design is finalized. Several sensors and microcontrollers have been ordered by the clients for familiarizing ourselves with. The implementation plans for all components are finished. We finished our design document, and progress report. Our clients told us to go study sensor interfacing with the microcontroller, back end database implementation, data visualization, and the Wi-Fi interface of the microcontroller. 

\subsubsection{Problems}

None

\subsubsection{Solutions}

None

\end{document}

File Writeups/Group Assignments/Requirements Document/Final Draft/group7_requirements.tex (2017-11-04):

\documentclass[IEEEtran,letterpaper,10pt,titlepage,fleqn,draftclsnofoot,onecolumn]{article}
%notitlepage vs titlepage
%fleqn left align

%\usepackage{nopageno} %no page numbers
\usepackage{indentfirst}
\usepackage{alltt}                                           
\usepackage{float}
\usepackage{color}
\usepackage{url}
\usepackage[utf8]{inputenc}

\usepackage{graphicx}                                        
\usepackage{amssymb}                                         
\usepackage{amsmath}                                         
\usepackage{amsthm}                                          

\usepackage{balance}
%\usepackage[TABBOTCAP, tight]{subfigure}
\usepackage{enumitem}
\usepackage{pstricks, pst-node}
\usepackage{geometry}
\usepackage{hyperref}
\usepackage{textcomp}
\usepackage{listings}
%allows for code snipets

\geometry{textheight=9.5in, textwidth=7in} 

\newcommand{\cred}[1]{{\color{red}#1}} %think function call, changes text to red
\newcommand{\cblue}[1]{{\color{blue}#1}} %text to blue
\definecolor{dkgreen}{rgb}{0,0.6,0}
\definecolor{gray}{rgb}{0.5,0.5,0.5}
\definecolor{mauve}{rgb}{0.58,0,0.82}
\lstset{frame=tb,
  language=c,
  aboveskip=3mm,
  belowskip=3mm,
  showstringspaces=false,
  columns=flexible,
  basicstyle={\small\ttfamily},
  numbers=none,
  numberstyle=\tiny\color{gray},
  keywordstyle=\color{blue},
  commentstyle=\color{dkgreen},
  stringstyle=\color{mauve},
  breaklines=true,
  breakatwhitespace=true,
  tabsize=3
}

\def\name{Brandon Ellis, Jiayu Han, and Jack Neff}
\def\class{CS 461 }
\def\assignment{Requirements}

%PDF Properties
\hypersetup{
  colorlinks = true,
  urlcolor = black,
  pdfauthor = {\name},
  pdfkeywords = {cs461 ``Senior Capstone' Requirements},
  pdftitle = {\class \assignment},
  pdfsubject = {\class \assignment},
  pdfpagemode = UseNone
}

\begin{document}

%TitlePage
\begin{titlepage}
	\begin{center}
		\vspace*{1cm}
		
		\huge
		\textbf{Green Smart Gardening System: Requirements}
        
        \vspace{1.5cm}
        
		\large
        \textbf{Brandon Ellis, Jiayu Han, and Jack Neff}
		
		\vspace{5cm}
    
    \large
    Abstract
    
    \vspace{5mm}
    
    \normalsize
    The purpose of this document is to describe the requirements that must be fulfilled for our Green Smart Gardening System to be considered complete. It includes design requirements, such as environmental sensors; performance requirements, which dictate things like the frequency of environmental sampling; and client requirements, specifically the use of solar power.
		
		\vfill
        
		\large
        CS 461\\
        Fall Term\\
    \end{center}
\end{titlepage}

\huge
Contents

\vspace{5mm}

\large
1 Introduction

\vspace{1mm}

\normalsize
1.1 Overview

\vspace{5mm}

\large
2 Overall Description

\vspace{1mm}

\normalsize
2.1 Product Perspective

\vspace{1mm}

\small
2.1.1 User Interface

\vspace{1mm}

\small
2.1.2 Hardware Devices

\vspace{1mm}

\small
2.1.3 Memory Operations

\vspace{1mm}

\small
2.1.4 Site Adaptation Requirements

\vspace{1mm}

\normalsize
2.2 Product Functions

\vspace{1mm}

\normalsize
2.3 User Characteristics

\vspace{1mm}

\normalsize
2.4 Constraints

\vspace{1mm}

\small
2.4.1 Safety

\vspace{1mm}

\small
2.4.2 Hardware

\vspace{1mm}

\normalsize
2.5 Assumptions

\vspace{5mm}

\large
3 Specific Requirements

\normalsize
3.1 Client Requirements

\vspace{1mm}

\normalsize
3.2 Customer User Stories

\vspace{1mm}

\normalsize
3.3 Technical Requirements

\vspace{1mm}

\normalsize
3.4 Project Timeline

\vspace{1mm}

\normalsize
3.5 Stretch Goals

\clearpage

\section{Introduction}

Our Green Smart Gardening System(GSGS) will be a prototype of a green energy powered Internet-of-Thing device focusing on the environmental condition monitoring and collecting by using multiple sensors with a micro-controller. The system will transfer the collected data to a computer for analyzing and helping user to adjust the factors.

\subsection{Overview}

The rest of this document will cover a more in depth discussion of further requirements. Initially, this will be broken into two larger topics. The first topic is the Overall Description. It will touch on Product Perspective, the device need storage to store data and computer to analyze and display data; Product Functions, the device monitoring the gardening factors and help user to adjust those factors; User Characteristics, which will be from beginning level users to industries; Constraints, the device need to be waterproof and large battery capacity because of the weather in Oregon; and Assumptions \& Dependencies, what our backup plans are for analyzing and scheduling.

\vspace{5mm}

Second is the topic of Specific Requirements. It will include the Client Requirements, that it needs to be powered by solar energy; Customer User Stories, what users want from this device for both individual and industries; Technical Requirements, the ranking of importance for all sections of this project; Project Timeline, our estimated progress schedule; and Stretch Goals, some features we may want to add after the project is done. 

\section{Overall Description}
\subsection{Product Perspective}
\subsubsection{User Interface}

The user interface will provide the user with information about their garden. This will display information from all the sensors (soil moisture, air temperature, soil pH, etc.) in a variety of relevant ways. Users will be able to view the current status of the garden through the web browser, as well as a record of periodical updates that the system will be continuously sending. In addition, algorithms we write will analyze this record and try to find correlations between data sets that can be displayed to the user in graphical form. The user interface will be stored on a web server and available on any device with an internet connection. User will be able to read the data by graph over time on the web browser.

\subsubsection{Hardware Devices}

The hardware devices required are a microcontroller with wireless connectivity and an array of sensors that can connect to the microcontroller. A solar power source is required, as well as a battery capable of sustaining the device through the typical overcast season in the Willamette Valley. Access to a computer will be necessary for analysis and viewing of the data, as a microcontroller will not be powerful enough to perform the necessary calculation, and does not have a good enough graphical display to produce tables and graphs. To achieve the aforementioned wireless connectivity, at a range ideal for a commercial garden, the final hardware component is a wi-fi module for the microcontroller. Two additional devices, used to achieve stretch goals, are a smartphone and a bluetooth module. These are elaborated on in the section Stretch Goals.

\subsubsection{Memory Operations}

We will need a database to store packets of environmental information in, and for ease of access when analyzing it. The sensors themselves do not need memory, but the microcontroller should probably have a limited amount of memory, in case the internet connection goes bad. If it can store several packets in memory, it can stockpile those packets and transmit them when the connection is restored.  

\clearpage

\subsubsection{Site Adaptation Requirements}

We will need to construct a garden and seed some plants, recording environmental data and plant growth data over a period of time. We will need a bed of soil with adequate drainage and sunlight, and places to install all the environmental sensors we want to use. The location must also have an internet connection, so the data can be relayed to the database from the microcontroller. 

\subsection{Product Functions}

The Green Smart Gardening System (Working Title) is a data collection and analysis system for vineyards. It uses sensors of a variety of environmental conditions connected to a centralized microcontroller to analyze patterns of plant growth. We will use proprietary algorithms to analyze and display this data to users. This can help the user make informed decisions, on issues like the quantity of watering and need for fertilizer, with more in depth data then they have previously had access to. On a larger scale, this system will monitor berry farms or vineyards, help their owner manage them, and possibly connect to other similar systems in the area in order to gather more data and get more accurate readings. 

\subsection{User Characteristics}

The original use case for this device was framed around the Southern Oregon Wine Industry. We intend for it to stay true to that in making our device accessible to a more amatuer user, while broadening the use to recreational as well as industrial gardening. Users will be assumed to be more skilled in gardening than computer usage. Accordingly, the interface must be simple and intuitive, and as helpful as possible with tips to increase plant growth and maintain optimal conditions.   

\subsection{Constraints}
\subsubsection{Safety}

Due to the fact that we plan on having a device that can perform in the elements, there needs to be some care given to ensuring it can do this safely. We can addresses this in two separate ways. First, we can protect connections between the device and sensors. This will prevent potentially hazardous shorts and improve the longevity of our device. Second, components that do not require interaction with the elements can be put in a housing device. This will make sure that at least the microcontroller and battery are not unnecessarily exposed to wear. 

\subsubsection{Hardware}

Our chief software constraints are in the vein of power supply. We have decided to implement a solar component into the system, so when possible, the system will run on solar power and use any excess energy collected to charge its battery. Oregon’s Willamette Valley, where we envision this product, sees significantly reduced sunlight during the Winter. This affects the battery sizes we will use, which must be made large enough to support their components through these months. In addition to larger batteries, sensors and the microcontroller will need to be as efficient as possible, transmitting information at relatively long intervals. The other main constraint besides power for the microcontroller is the memory. The more storage, the more expensive the microcontroller and often the higher the power use, but information is better backed-up if there is something wrong with the connection.   

\subsection{Assumptions}

We assume that the sensors we select will be able to interact with our microcontroller. If not, we will need to replace the sensors or microcontroller. We assume we will be able to collect data in a synchronous way with multiple sensors. If not, we will need to design more complex analysis algorithms, which will take more time. We will, based on calculations, assume our battery setup will last from installation well into the Spring of 2018. If not we need to recalculate and either increase battery life or decrease power usage. We assume we will be able to algorithmically analyze the best way to treat a plant based on data. If not, we may need to do some research on plants and take a more educated approach to the algorithms.

\clearpage

\section{Specific Requirements}
\subsection{Client Requirements}

A key requirement that our clients are asking for is that our device is powered through green method. The specific method requested is solar. To this end our device will have a solar panel that will feed into a rechargeable battery, fulfilling our client’s requirement and ensuring that our device is sustainable and does not require constant battery changes.

\subsection{Customer User Stories}

\begin{itemize}
  \item As the owner of a garden, I can check the environmental data of my garden so that I can make informed decisions about my plants’ health.
  \item As the user of a smart gardening device, I can access my device in such a way that it is intuitive to use.
  \item As the owner of a smart gardening device, I can trust that my device will have a sustainable power system such that I do not have to switch batteries frequently.
  \item As the owner of an industrial farm, I know my device can weather the elements such that I don’t have to perform maintenance and replace parts.
  \item As a smart gardening device user, I can view the data of my garden in such a way that it is easily accessible and readable without having to physically check the device.
\end{itemize}

\subsection{Technical Requirements}

The following is a list of hierarchical requirements to create the base version of our device. The element of hierarchy dictates which requirements are dependent on their predecessors. This information is also shown in the form of a Gantt chart below. 

\begin{itemize}
  \item Assemble board, sensors, wireless output method, and provide solar power to the device.
  \item Create software interfaces between sensors and board.
  \item Ensure collected data from sensors can be saved to an SD card.
  \item Establish connection between wireless device and external storage system.
  \item Validate that retrieved data matches confirmed environmental conditions.
  \item Create a user interface that outputted data can be viewed through.
\end{itemize}

\subsection{Project Timeline}

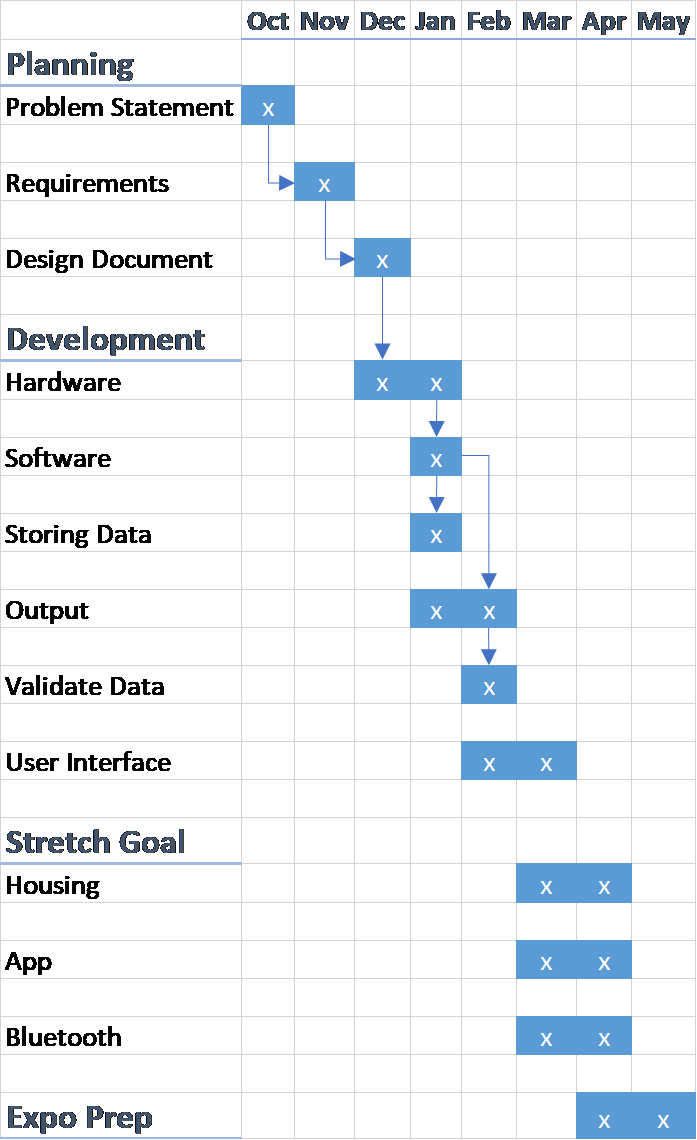
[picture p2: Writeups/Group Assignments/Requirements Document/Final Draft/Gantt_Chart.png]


\subsection{Stretch Goals}

When all of the base requirements have been established, there are a few stretch goals that can be attained. The first is a housing for the created device. This would protect it from the elements, with the exception of sensors that would require being external. Additionally, it would be a finalizing touch to have the sensitive internal device contained within one protective unit. The second goal is the creation of an app. This app would enable the user to view their data in a much more mobile manner. The app would connect to whatever database is utilized to house what the device has outputted. The third goal is another form of wireless connection.This be filled through the addition of a Bluetooth module to our device. This would open up another possible mode for user connectivity, possibly through the aforementioned app.

\end{document}

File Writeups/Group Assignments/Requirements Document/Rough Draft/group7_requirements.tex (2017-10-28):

\documentclass[IEEEtran,letterpaper,10pt,titlepage,fleqn,draftclsnofoot,onecolumn]{article}
%notitlepage vs titlepage
%fleqn left align

%\usepackage{nopageno} %no page numbers
\usepackage{indentfirst}
\usepackage{alltt}                                           
\usepackage{float}
\usepackage{color}
\usepackage{url}

\usepackage{graphicx}                                        
\usepackage{amssymb}                                         
\usepackage{amsmath}                                         
\usepackage{amsthm}                                          

\usepackage{balance}
%\usepackage[TABBOTCAP, tight]{subfigure}
\usepackage{enumitem}
\usepackage{pstricks, pst-node}
\usepackage{geometry}
\usepackage{hyperref}
\usepackage{textcomp}
\usepackage{listings}
%allows for code snipets

\geometry{textheight=9.5in, textwidth=7in} 

\newcommand{\cred}[1]{{\color{red}#1}} %think function call, changes text to red
\newcommand{\cblue}[1]{{\color{blue}#1}} %text to blue
\definecolor{dkgreen}{rgb}{0,0.6,0}
\definecolor{gray}{rgb}{0.5,0.5,0.5}
\definecolor{mauve}{rgb}{0.58,0,0.82}
\lstset{frame=tb,
  language=c,
  aboveskip=3mm,
  belowskip=3mm,
  showstringspaces=false,
  columns=flexible,
  basicstyle={\small\ttfamily},
  numbers=none,
  numberstyle=\tiny\color{gray},
  keywordstyle=\color{blue},
  commentstyle=\color{dkgreen},
  stringstyle=\color{mauve},
  breaklines=true,
  breakatwhitespace=true,
  tabsize=3
}

\def\name{Brandon Ellis, Jiayu Han, and Jack Neff}
\def\class{CS 461 }
\def\assignment{Requirements}

%PDF Properties
\hypersetup{
  colorlinks = true,
  urlcolor = black,
  pdfauthor = {\name},
  pdfkeywords = {cs461 ``Senior Capstone' Requirements},
  pdftitle = {\class \assignment},
  pdfsubject = {\class \assignment},
  pdfpagemode = UseNone
}

\begin{document}
%TitlePage
\begin{titlepage}
	\begin{center}
		\vspace*{1cm}
		
		\huge
		\textbf{Green Smart Gardening System: Requirements}
        
        \vspace{1.5cm}
        
		\large
        \textbf{Brandon Ellis, Jiayu Han, and Jack Neff}
		
		\vspace{5cm}
    
    \normalsize
    The purpose of this document is to describe the requirements that must be fulfilled for our Green Smart Gardening System to be considered complete. It includes design requirements, such as environmental sensors; performance requirements, which dictate things like the frequency of environmental sampling; and client requirements, specifically the use of solar power.
		
		\vfill
        
		\large
        CS 461\\
        Fall Term\\
    \end{center}
\end{titlepage}

\section{Introduction}

Our Green Smart Gardening System(GSGS) will be a prototype of a green energy powered Internet-of-Thing device focusing on the environmental condition monitoring and collecting by using multiple sensors with a micro-controller. The system will transfer the collected data to a computer for analyzing and helping user to adjust the factors.

\subsection{Definitions}

\begin{itemize}
  \item GSGS - Green Smart Gardening System
  \item IOT  - Internet-of-Things
\end{itemize}

\subsection{Overview}

The rest of this document will cover a more in depth discussion of further requirements. Initially, this will be broken into two larger topics. The first topic is the Overall Description. It will touch on Product Perspective, the device need storage to store data and computer to analyze and display data; Product Functions, the device monitoring the gardening factors and help user to adjust those factors; User Characteristics, which will be from beginning level users to industries; Constraints, the device need to be waterproof and large battery capacity because of the weather in Oregon; and Assumptions \& Dependencies, what our backup plans are for analyzing and scheduling.

\vspace{5mm}

Second is the topic of Specific Requirements. It will include the Client Requirements, that it needs to be powered by solar energy; Customer User Stories, what users want from this device for both individual and industries; Technical Requirements, the ranking of importance for all sections of this project; Project Timeline, our estimated progress schedule; and Stretch Goals, some features we may want to add after the project is done. 

\section{Overall Description}
\subsection{Product Perspective}
\subsubsection{User Interface}

The user interface will provide the user with information about their garden. This will display information from all the sensors in a variety of relevant ways. Users will be able to view the current status of the garden in real time, as well as a record of periodical updates that the system will be continuously sending. In addition, algorithms we write will analyze this record and try to find correlations between data sets that can be displayed to the user in graphical form.   

\subsubsection{Hardware Devices}

The hardware devices required are a microcontroller with internet capability, and an array of sensors that can connect to the microcontroller. A solar power source is required, as well as a battery capable of lasting through the typical overcast season in the Willamette Valley. Access to a computer will be necessary for analysis and viewing of the data, as to not require the user to physically check the device.

\subsubsection{Memory Operations}

We will need a database to store packets of environmental information in, and for ease of access when analyzing it. The sensors themselves do not need memory, but the microcontroller should probably have a limited amount of memory, in case the internet connection goes bad. If it can store several packets in memory, it can stockpile those packets and transmit them when the connection is restored.  

\subsubsection{Site Adaptation Requirements}

We will need to construct a garden and seed some plants, recording environmental data and plant growth data over a period of time. We will need a bed of soil with adequate drainage and sunlight, and places to install all the environmental sensors we want to use. The location must also have an internet connection, so the data can be relayed to the database from the microcontroller. 

\subsection{Product Functions}

The Green Smart Gardening System (Working Title) is a data collection and analysis system for vineyards. It uses sensors of a variety of environmental conditions connected to a centralized microcontroller to analyze patterns of plant growth. We will use proprietary algorithms to analyze and display this data to users. Hopefully, when the gardening system has collected enough information, it will be able to suggest increases or decreases of water application based on current conditions. On a large scale, this system will monitor berry farms or vineyards, help their owner manage them, and possibly connect to other similar systems in the area in order to gather more data and get more accurate readings. 

\subsection{User Characteristics}

The original use case for this device was framed around the Southern Oregon Wine Industry. We intend for it to stay true to that in making our device accessible to a more amatuer user, while broadening the use to recreational as well as industrial gardening. Users will be assumed to be beginner level skill in both gardening and computer usage. Accordingly, the interface must be simple and intuitive, and as helpful as possible with tips to increase plant growth and maintain optimal conditions.   

\subsection{Constraints}
\subsubsection{Safety}

Due to the fact that we plan on having a device that can perform in the elements, there needs to be some care given to ensuring it can do this safely. We can addresses this in two separate ways. First, we can protect connections between the device and sensors. This will prevent potentially hazardous shorts and improve the longevity of our device. Second, components that do not require interaction with the elements can be put in a housing device. This will make sure that at least the microcontroller and battery are not unnecessarily exposed to wear. 

\subsubsection{Hardware}

Our chief software constraints are in the vein of power supply. We have decided to implement a solar component into the system, so when possible, the system will run on solar power and use any excess energy collected to charge its battery. Oregon’s Willamette Valley, where we envision this product, sees significantly reduced sunlight during the Winter. This affects the battery sizes we will use, which must be made large enough to support their components through these months. In addition to larger batteries, sensors and the microcontroller will need to be as efficient as possible, transmitting information at relatively long intervals. The other main constraint besides power for the microcontroller is the memory. The more storage, the more power use, but also the better backed-up information is if there is something wrong with the connection.   

\subsection{Assumptions}

We assume that the sensors we select will be able to interact with our microcontroller. If not, we will need to replace the sensors or microcontroller. We assume we will be able to collect data in a synchronous way with multiple sensors. If not, we will need to design more complex analysis algorithms, which will take more time. We will, based on calculations, assume our battery setup will last from installation well into the Spring of 2018. If not we need to recalculate and either increase battery life or decrease power usage. We assume we will be able to algorithmically analyze the best way to treat a plant based on data.If not, we may need to do some research on plants and develop a more educated approach.  

\clearpage

\section{Specific Requirements}
\subsection{Client Requirements}

A key requirement that our clients are asking for is that our device is powered through green method. The specific method requested is solar. To this end our device will have a solar panel that will feed into a rechargeable battery, fulfilling our client’s requirement and ensuring that our device is sustainable and does not require constant battery changes.

\subsection{Customer User Stories}

\begin{itemize}
  \item As the owner of a garden, I can check the environmental data of my garden so that I can make informed decisions about my plants’ health.
  \item As the user of a smart gardening device, I can access my device in such a way that it is intuitive to use.
  \item As the owner of a smart gardening device, I can trust that my device will have a sustainable power system such that I do not have to switch batteries frequently.
  \item As the owner of an industrial farm, I know my device can weather the elements such that I don’t have to perform maintenance and replace parts.
  \item As a smart gardening device user, I can view the data of my garden in such a way that it is easily accessible and readable without having to physically check the device.
\end{itemize}

\subsection{Technical Requirements}

The following is a list of hierarchical requirements to create the base version of our device. The element of hierarchy dictates which requirements are dependent on their predecessors. This information is also shown in the form of a Gantt chart below. 

\begin{itemize}
  \item Assemble board, sensors, wireless output method, and provide solar power to the device.
  \item Create software interfaces between sensors and board.
  \item Ensure collected data from sensors can be saved to an SD card.
  \item Establish connection between wireless device and external storage system.
  \item Validate that retrieved data matches confirmed environmental conditions.
  \item Create a user interface that outputted data can be viewed through.
\end{itemize}

\subsection{Project Timeline}

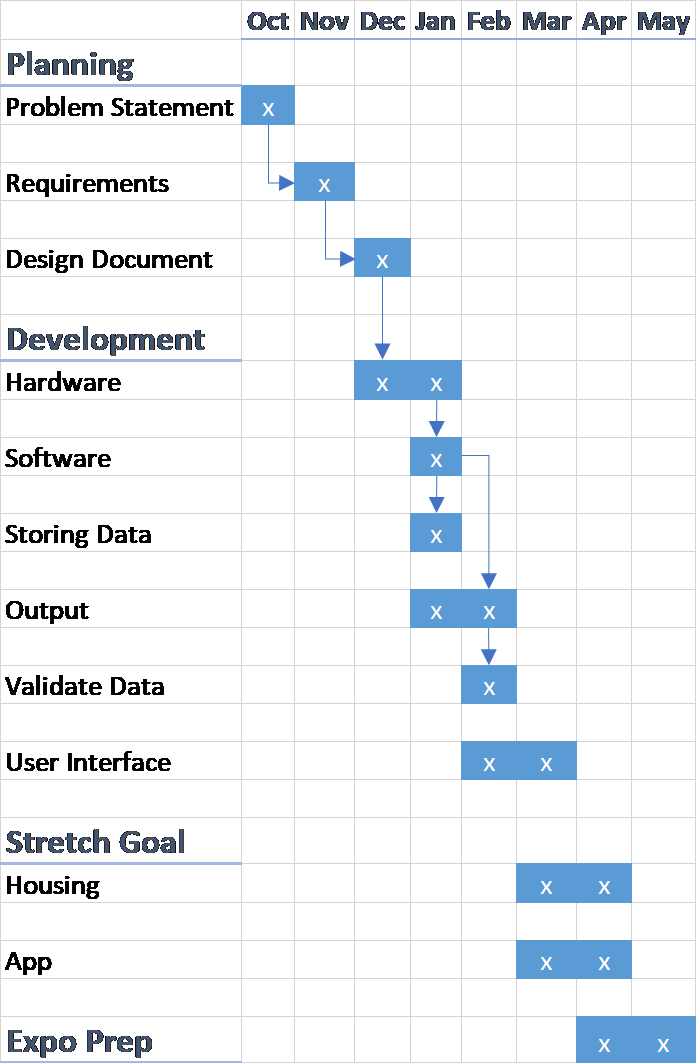
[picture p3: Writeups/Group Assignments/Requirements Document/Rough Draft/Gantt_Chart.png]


\subsection{Stretch Goals}

When all of the base requirements have been established, there are a couple stretch goals that can be attained. The first is a housing for the created device. This would protect it from the elements, with the exception of sensors that would require being external. Additionally, it would be a finalizing touch to have the sensitive internal device contained within one protective unit. The second goal is the creation of an app. This app would enable the user to view their data in a much more mobile manner. The app would connect to whatever database is utilized to house what the device has outputted.

\end{document}

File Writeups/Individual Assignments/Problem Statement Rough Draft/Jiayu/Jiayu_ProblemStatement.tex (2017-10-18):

\documentclass[letterpaper, fleqn, 10pt, onecolumn,singlespace]{article}

\title{Green Smart Gardening System: \newline Problem Statement}
\author{Jiayu Han CS-461  Fall 2017}
\begin{document}
\maketitle
\hrule

\begin{abstract}
	Our project is Green Smart Gardening System. By definition, it will be a green energy powered Internet-of-Thing(IOT) device that monitors and analyses the environmental conditions, like temperature, humidity and soil moisture. And it will create a better model of the plants growing patterns based on the analysis, which will interact with the existing smart home equipment to provide a better growing environment for all kinds of plants. Commercial wise, client has a vision to promote this Green Smart Gardening System to Oregon wine industry since grapes` quality occupied a great percentage in quality of the wine. 
\end{abstract}

\pagebreak

\section*{Definition and Description}
	The Gardening system has not been easy for either industry or family. It is hard to create the best growing environment for different kinds of plants and measuring the plants health data. For individuals, it is hard to properly nursing plants. Most people learned how to nurse their plants by reading or researching online, which is usually different from their environment. They will face different kinds of uncommon health status or disease, which caused by their unique environments. For industries like Oregon wine industry, it is essential to have great grape quality for the wine brewing.  Grapes requires certain temperature at daytime and nighttime, and humidity for its growing and sweetness. 
\newline
	Our project, Green Smart Gardening System, is a green energy powered Internet-of-Thing(IOT) device that monitors and analyses the environmental conditions, like temperature, humidity and soil moisture. The analysis will help to create a better model of the plants growing patterns by measuring the plants health status. 

\section*{Proposed solution}
	Our Green Smart Gardening System will be a prototype of green energy powered IOT device focusing on the environmental condition monitoring and collecting by using multiple sensors with a micro-controller. The system will be an outdoor green energy powered device, which preferably to use solar with solar battery, and it is supposed to be rain-prove system due to the high percentage of rain in Oregon. By collecting data including temperature, humidity and soil moisture, the sensors will send the data into a central computer wirelessly. Data will be transferred from sensors to computer remotely through the micro-controller, which has not been determined yet. We will find out the ideal micro-controller from the client list. After collecting the data into the database, we will analyze the all the environmental factors using algorithm to find out the best growing environmental factors for the plants. Then the system will adjust the growing environment by interacting with the existing smart gardening system.  

\section*{Performance Metrics}
	A prototype of the smart gardening system with 
\newline
(1)	Basic environment monitoring capability (e.g. soil moisture, temperature, humility, and air condition, etc.) using green energy
\newline
(2)	Transfer captured data into a computer for data analysis
\newline
(3) It has to be reliable and consistent(Don`t have to change battery or sensors at least within a year)
\newline
(4)	Transmit analyzed data into a phone or another device wirelessly (optional)
\newline
(5)	Build data analytic model for plants health verse environment factors (optional)

\end{document}

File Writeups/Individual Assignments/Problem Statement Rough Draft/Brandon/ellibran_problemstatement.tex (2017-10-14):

\documentclass[IEEEtran,letterpaper,10pt,titlepage,fleqn,draftclsnofoot,onecolumn]{article}
%notitlepage vs titlepage
%fleqn left align

%\usepackage{nopageno} %no page numbers
\usepackage{indentfirst}
\usepackage{alltt}                                           
\usepackage{float}
\usepackage{color}
\usepackage{url}

\usepackage{graphicx}                                        
\usepackage{amssymb}                                         
\usepackage{amsmath}                                         
\usepackage{amsthm}                                          

\usepackage{balance}
%\usepackage[TABBOTCAP, tight]{subfigure}
\usepackage{enumitem}
\usepackage{pstricks, pst-node}
\usepackage{geometry}
\usepackage{hyperref}
\usepackage{textcomp}
\usepackage{listings}
%allows for code snipets

\geometry{textheight=9.5in, textwidth=7in} 

\newcommand{\cred}[1]{{\color{red}#1}} %think function call, changes text to red
\newcommand{\cblue}[1]{{\color{blue}#1}} %text to blue
\definecolor{dkgreen}{rgb}{0,0.6,0}
\definecolor{gray}{rgb}{0.5,0.5,0.5}
\definecolor{mauve}{rgb}{0.58,0,0.82}
\lstset{frame=tb,
  language=c,
  aboveskip=3mm,
  belowskip=3mm,
  showstringspaces=false,
  columns=flexible,
  basicstyle={\small\ttfamily},
  numbers=none,
  numberstyle=\tiny\color{gray},
  keywordstyle=\color{blue},
  commentstyle=\color{dkgreen},
  stringstyle=\color{mauve},
  breaklines=true,
  breakatwhitespace=true,
  tabsize=3
}

\def\name{Brandon Ellis}
\def\class{CS 461 }
\def\assignment{Problem Statement}

%PDF Properties
\hypersetup{
  colorlinks = true,
  urlcolor = black,
  pdfauthor = {\name},
  pdfkeywords = {cs461 ``Senior Capstone' Problem Statement},
  pdftitle = {\class \assignment},
  pdfsubject = {\class \assignment},
  pdfpagemode = UseNone
}

\begin{document}
%TitlePage
\begin{titlepage}
	\begin{center}
		\vspace*{1cm}
		
		\huge
		\textbf{Green Smart Gardening System: Problem Statement}
        
        \vspace{1.5cm}
        
		\large
        \textbf{Brandon Ellis}
		
		\vspace{5cm}
		
		\normalsize
		This paper covers the challenges and solutions proposed in Green Smart Gardening System, an analytical smart gardening device. First, this paper will address the problem that our created device will seek to solve. It will then discuss the proposed solution, broken down into the device’s inputs, outputs, hardware, and analysis. Finally, this paper will conclude with the metrics which will define the completion of our device. This paper has been created prior to our first client meeting, as such some assumptions are being made and some requirements are noted to only be temporarily penned in.
		
		\vfill
        
		\large
        CS 461\\
        Fall Term\\
    \end{center}
\end{titlepage}

\section{Description of Problem}

As the use of smart home technology increases so has the interest in smart gardening. This presents an opportunity to create a device that can simplify some aspects of gardening and provide the user with more in-depth analysis of their garden. This device would enable the user to contrast the health of their plant with environmental statistics, making informed care of their garden that much easier. 

\vspace{5mm}

\section{Proposed Solution}

What this project is aiming to accomplish is the creation of an environmental monitoring device. While a specific microcontroller has yet to be determined, said device has a number of specific necessities. I will be breaking these specifics down into four portions: input, output, hardware, and analytics. 

\subsection{Input}

To fulfill the gardening aspect of this device, it tracks several environmental conditions. For soil, the device will measure the moisture level in the soil. Additionally, pending the meeting with our clients, the temperature of the soil may be measured. On the note of temperature, the ambient air temperature will be recorded. The air humidity and condition will also be noted.

\subsection{Output}

Once all of the above inputs have been recorded, the device needs to send them somewhere useful. There is one location planned currently for the data to go, but there are several routes that the data can take from it. First the data will always go to a computer for analysis. Once the data has been quantified, a couple different things could occur depending on our group’s initial and stretch goals. The first is that the data could be sent wirelessly to a smart phone or another smart device. From there, the user could reference a more viewable representation of the data at their leisure. The second tags on to outputting the data for viewing, a current stretch goal is the creation of a viewing model that would compare specifics plants’ health against noted environmental factors. Lastly, the computer would be able to interface with an existing smart home system to control environmental factors. These could include the ambient temperature, lighting, and sprinklers.

\subsection{Hardware}

To achieve this the microcontroller will have to be augmented slightly. First, the inputs require the device communicates with several sensors. Assuming a single connected sensor cannot collect multiple forms of environmental data, the device would need five sensors maximum. These will be for soil temperature, ambient temperature, soil moisture, air condition, and humidity.

\vspace{5mm}

Once the data has been collected, the microcontroller needs to output it. Depending on the direction of the project, the output could be done a couple of different ways. There will be a guaranteed connection from the device to a computer for the analysis of data. This will most likely be achieved by a wireless connection between the two, though it could be hardwired. When the data has been analyzed by the computer, there is a stretch goal that would connect said computer wirelessly to a smartphone or other internet enabled device. All of these result in the microcontroller needing at least one possible form of wireless output.

\vspace{5mm}

The last hardware requirement lies in how the device is powered. I key requirement is that the microcontroller be powered through green methods, with the preferred form being solar. This will mean that the device will most likely need to have a solar panel that feeds into a battery pack. This battery pack will then be what the microcontroller plugs into. By having a battery pack in the system, the device will be able to sustain power during night or when there are lower light levels.

\clearpage

\subsection{Analytics}

This bring us to the last piece of functionality, the analysis of data. There are two separate portions to this. The first analysis is done purely on the recorded data. After the microcontroller outputs raw data to a computer, an analytical model is required to be viewable. This model provide access all of outputted data. It does not contrast this information, instead simply making it accessible for the user to reference. The second form of analysis is currently a stretch goal. This analysis is on the aforementioned data once it has been outputted to the computer, but it does contrast the information against the general health and growth of a specific plant. At this point, how the health and growth is measured is undefined. Most likely these values will be inputted by the user, based on their insights and measurements.

\vspace{5mm}

\section{Performance Metrics}

For this project to be considered complete, there are several requirements. First, the microcontroller must receive valid, continuous, string of data from each of its inputs. This will result in the device collecting data, in designated intervals, on the soil, temperature, and air. Second, the microcontroller must be powered through solar energy. This will result in a green device, which is a key requirement for this project. Third, all captured data must be fed to a computer, and said computer must quantify all data for the user’s viewing. When these three tasks have been completed, the base specification of the device will be achieved.

\vspace{5mm}

To reach the full stretch goals for the project two more requirements must be met. The first is that once the data has reached the computer for analysis, it can be transmitted wirelessly for viewing on another device. The second stretch goal is the creation of an analytical model for comparing the health of a plant with the data received from the microcontroller. The health of the plant will, at this time, be defined by the user. This information would be viewed at either the main computer or sent wirelessly to a device. 

\end{document}

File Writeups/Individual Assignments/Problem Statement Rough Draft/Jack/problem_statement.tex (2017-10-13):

\documentclass[letterpaper, 10pt, fleqn]{article}

\title{Problem Statement}
\author{Jack Neff CS444 Fall2017}

\begin{document}
\maketitle
\hrule
\pagebreak

\begin{abstract}
	This system we seek to design is an internet-of-things device designed to independently manage gardens through collection and analysis of plant growth data. Automatic gardening systems are commonplace, but this system tryuly automates by learning from past experiences, and applying that information to future practices. We will be using some kind of microcontroller (more will be revealed when we meet the client) to control and monitor watering, temperature, and humidity. This central monitor will be linked via network to microcontrollers in the surrounding garden, which admisister the correct amount of water to each plant. The growth data can either be fed into the machine manually, or recorded by the networked microcontrollers and relayed to the central monitor. The end result should be a fully autonomous networked garden. 
\end{abstract}

\section{Problem Statement}

	We are designing a system that automatically nurses an array of plants. This problem, at a small scale, amounts to automatically tending a home garden, and learning from past data how to grow plants as large and healthy as possible. Unlike systems that operate on preset timers that need to be set by gardeners, what we are designing would analyze data obtained from its own measurements of plant growth and would learn to apply the correct amount of water for the right amount of time in any environmental state. This reduces to two main problems: the collection of data with the use of sensors, and the analysis of data with proprietary algorithms that guides the system to finding the "correct" thing to do. At a larger scale, this kind of system would be used on wineries, orchards, or farms to automatically tend to crops. It would reduce water use by avoiding overwatering or wasting of water.    

	This project, titled The Green Smart Gardening System, aims to monitor, analyze, and implement the findings of environmental factors and their relationship to plant growth. The goal here is to have multiple sensors that monitor humidity, temperature, and soil moisture, and plant growth, and to feed the data from those sensors into a central computer that analyzes it and returns the results to the main controller. In this way, the system learns what watering techniques work best under different conditions, and can calculate the ratio of resource expenditure to plant growth to factor in to its analysis. Monitoring lots of different environmental factors will be difficult, and it will require a lot of experimentation to make sure our sensors are picking up data correctly. We also need a way to reliably transfer data from those sensors to a remote device, and a way to prevent the sensors from dying for lack of charge. If we can, we will solar power them, likely with a backup battery.   

	To implement this, we will need to acquire one or more humidity, temperature, and moisture sensors that can remotely transmit data. We need to connect them all to a centralized microcontroller. The type of microcontroller is to be determined. Our clients have a list for us, from which we will select one that is optimized to meet our computational requirements at a minimal power consumption. Data recieved by the microcontroller will be transmitted to a remote database storage, where an offsite computer will analyze the data, and then pass to the microcontroller an analysis that informs its function. In order to translate collected data into an action plan for the system, we will need to write algorithms that take environmental factors as variables, and solve for the amount of water to give to a plant or area. 

	Analyzing the data and coming to a conclusion about it will be difficult. We will not be able to test extensively unless we use a lot of equipment and plant a lot of pots, given the time constraint and the amount of time it takes to grow a plant. Hopefully we will be able to collect enough data to perfrom our own analysis and write a specified algorithm. If we are, writing the algorithm will take some statistics research and some preliminary botany research. We also need to design an database capable of storing the correct symbols, and a network that can transmit data from a garden to a computer over the internet. 

	The microcontroller will need internet capability, and preferably some file transfer protocol. A program will need to be written to recieve, assemble, send, and parse data. It will be reliable but as energy efficient as it can be. One piece of design I would like to implement is the capability of the microcontroller to read that a sensor's battery is low, and send that information to the remote database, where it provides the connected computer with an alert. We will go one of two ways on the microcontroller in terms of user interface: either it is a modem-like, out-of-sight box, that operates basically self-contained, or an ipad-style interface with a great deal of user interaction. On an ipad interface, we could provide users with a nice looking display of collected data, in graph form. Even if we use the modem design, this data could be displayed on the connected computer.  

	The binding principle behind this whole project is that it is fully automated and sustainable. It manages itself in terms of function and energy usage, and only needs to be interacted with to perform maintenance. To accomplish this, not only the microcontroller, but all of the sensors need to be solar powered. Also, the central monitor needs to be constantly recieving new information to adjust its settings. In order to analyze the data, it needs to be beamed to the cloud, since the microcontroller will not be able to handle analysis computationally, and is restricted to local data anyway. However, the sensors shouldn't all connect to the cloud. To make things more efficient, the sensors should send their data to the microcontroller, which connects to the internet and sends the data to the cloud. In return it recieves an updated, analyzed series of data packets that tell it what to do with the conditions specified. This data is then implemented by the microcontroller. 

\end{document}

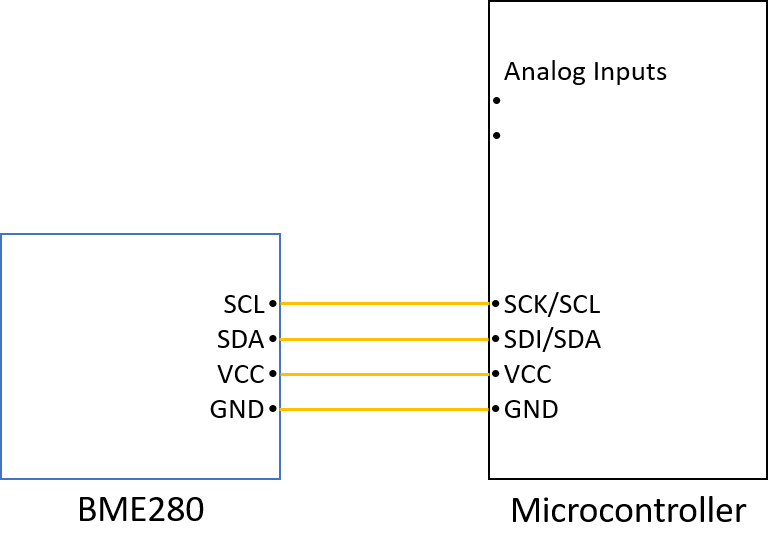
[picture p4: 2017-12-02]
Writeups/Group Assignments/Design Document/bme280_hookup.png

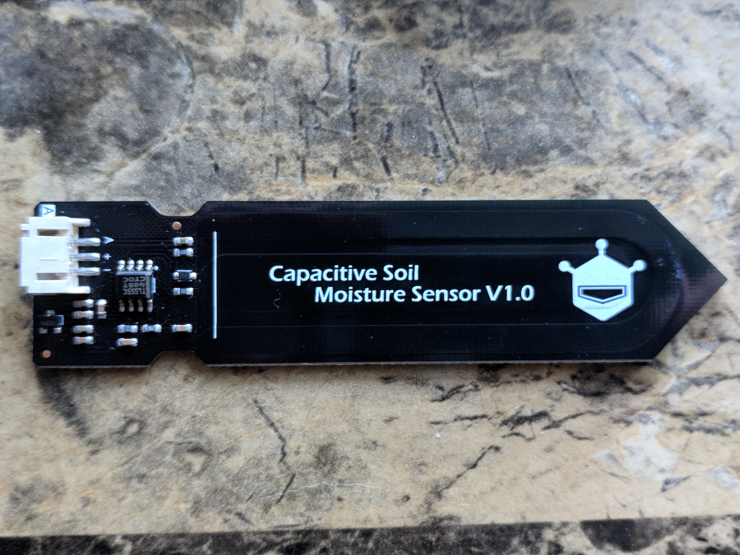
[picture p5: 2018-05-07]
Writeups/Group Assignments/Progress Reports/Spring Term/Midterm Report/soil_sensor.jpg

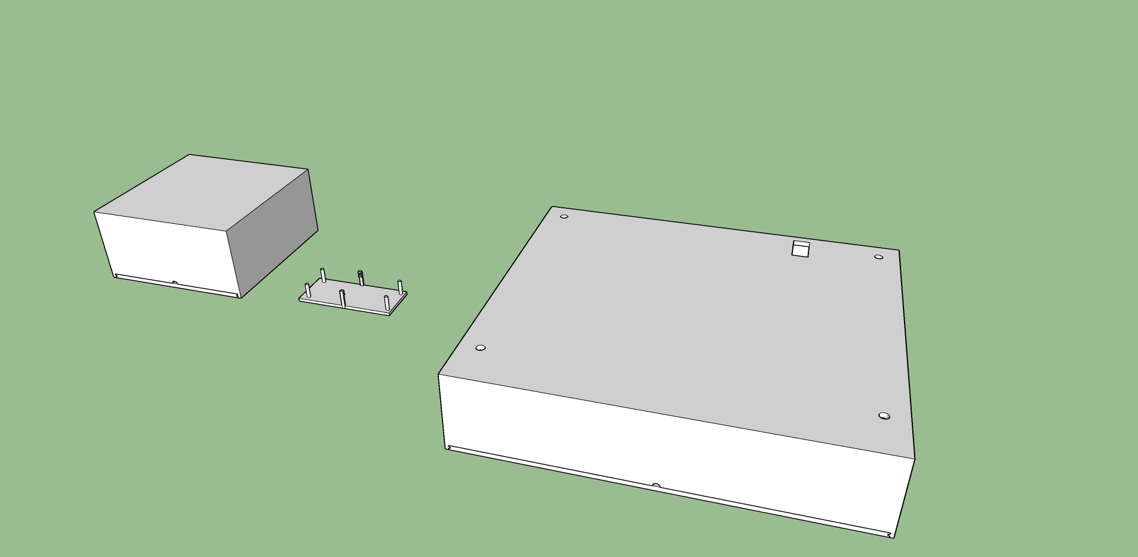
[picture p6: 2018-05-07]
Writeups/Group Assignments/Progress Reports/Spring Term/Midterm Report/packaging.jpg

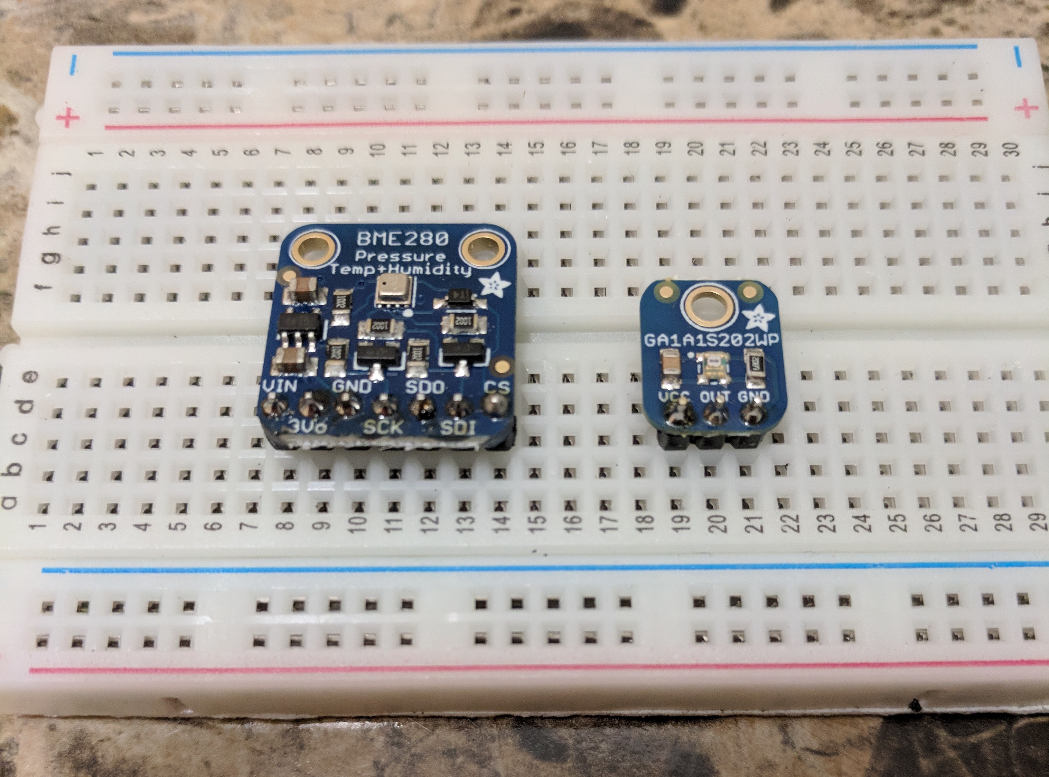
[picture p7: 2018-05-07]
Writeups/Group Assignments/Progress Reports/Spring Term/Midterm Report/air_light_sensors.jpg

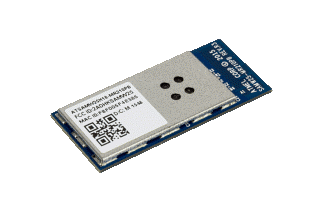
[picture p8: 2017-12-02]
Writeups/Group Assignments/Design Document/wifi_graphic.png

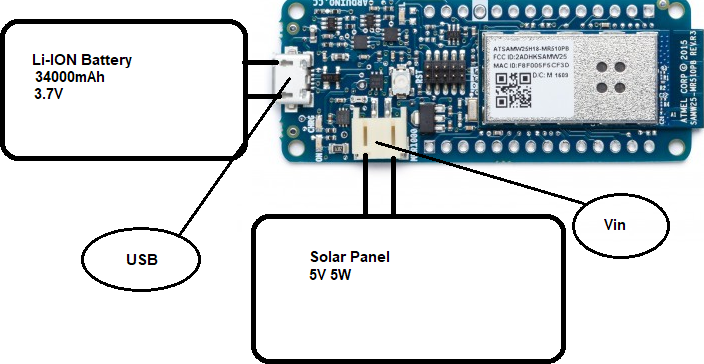
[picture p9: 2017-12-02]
Writeups/Group Assignments/Design Document/power_graphic_1.png

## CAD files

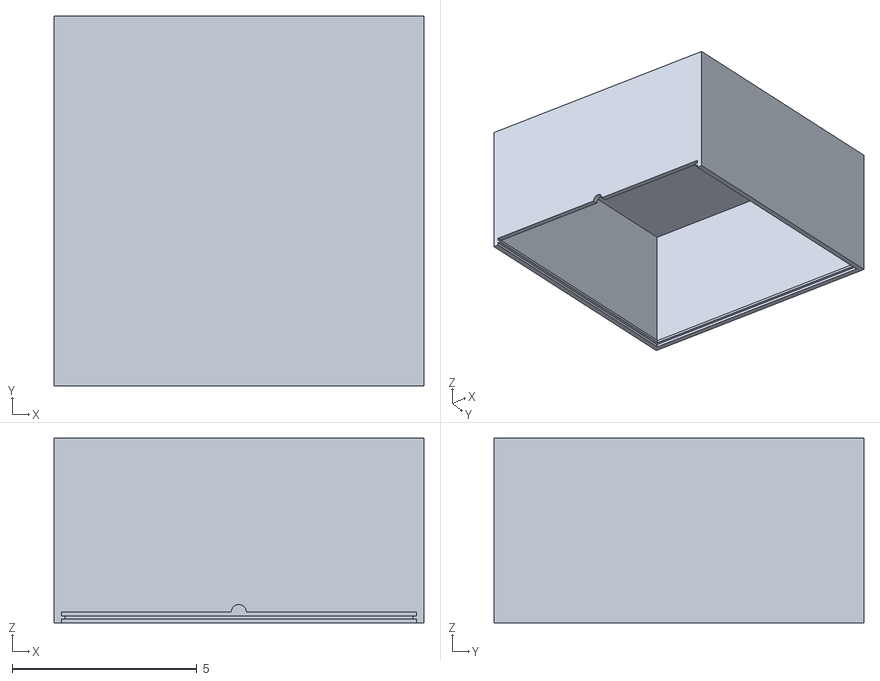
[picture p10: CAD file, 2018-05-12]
3D Model/Main.stl
10.0 x 10.0 x 5.00

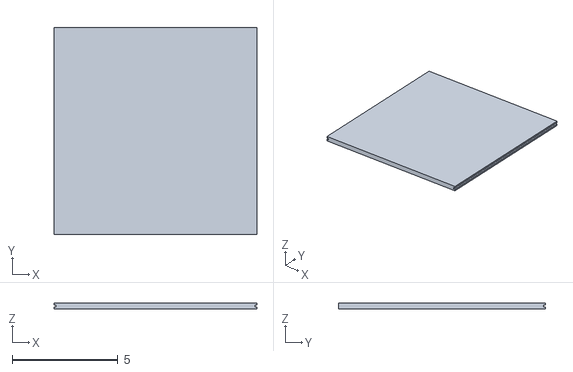
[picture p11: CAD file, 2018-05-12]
3D Model/Mainlip.stl
9.60 x 9.80 x 0.3

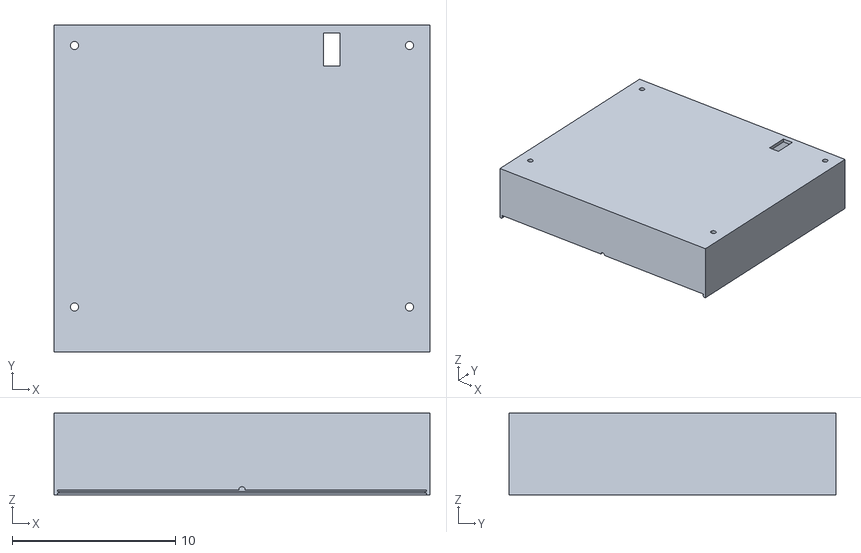
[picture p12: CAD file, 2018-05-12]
3D Model/Solar.stl
23.0 x 20.0 x 5.00

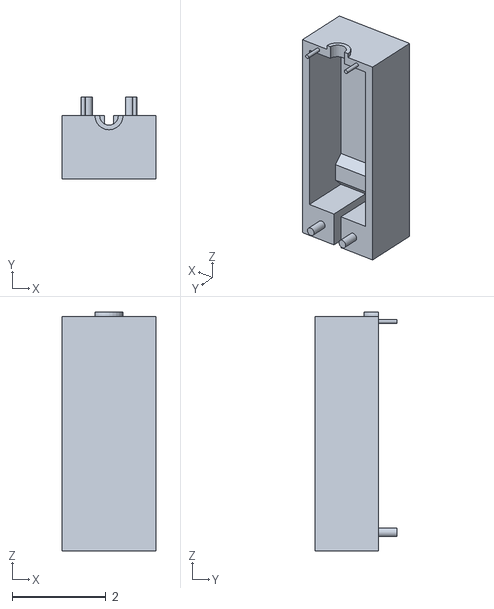
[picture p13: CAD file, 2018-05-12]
3D Model/SoilLeft.stl
2.00 x 1.75 x 5.10

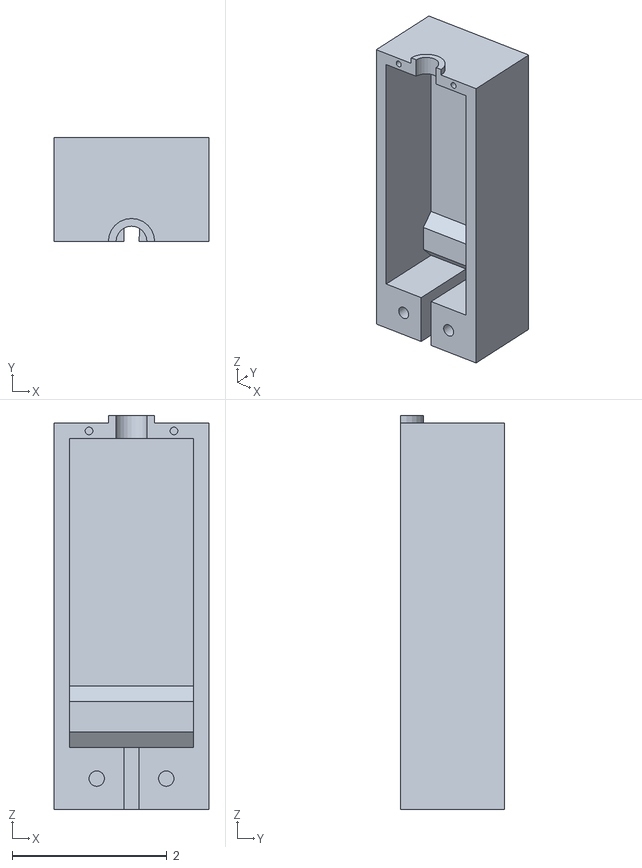
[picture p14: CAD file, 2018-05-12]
3D Model/SoilRight.stl
2.00 x 1.35 x 5.10

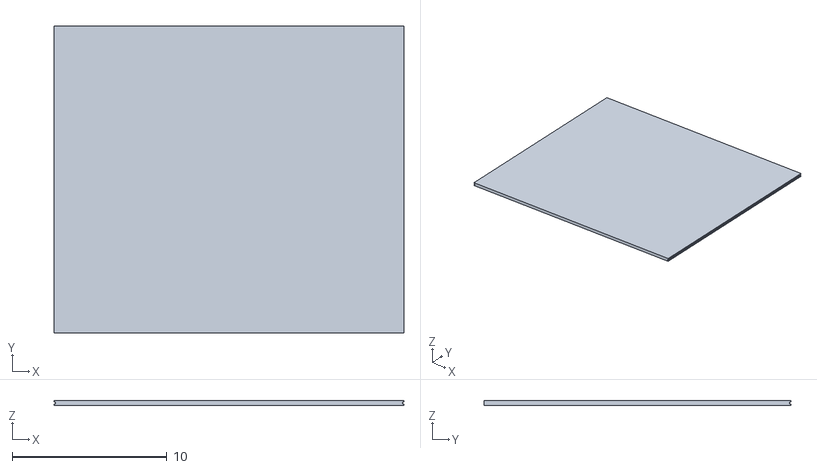
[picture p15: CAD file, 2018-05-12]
3D Model/SolarLid.stl
22.6 x 19.8 x 0.3

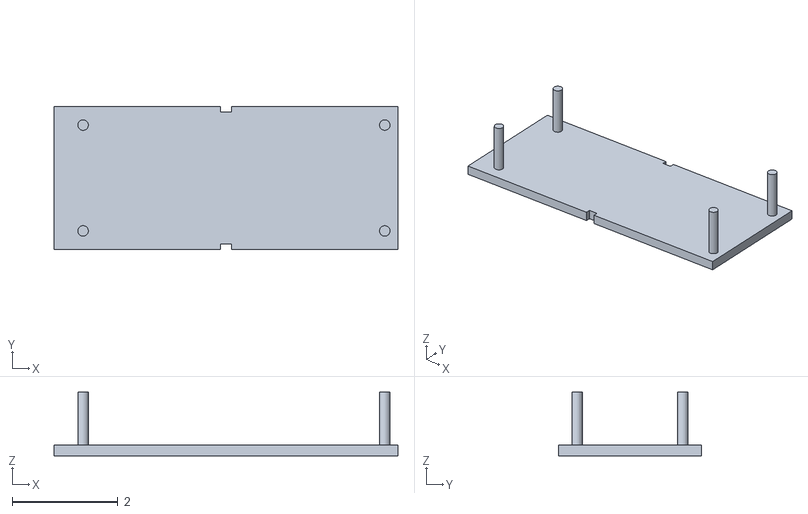
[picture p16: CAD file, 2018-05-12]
3D Model/MKR.stl
6.50 x 2.70 x 1.20

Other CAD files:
3D Model/MKR.skp
3D Model/Main.skp
3D Model/Mainlip.skp
3D Model/Soil moisture sensor packaging (left).skp
3D Model/Soil moisture sensor packaging (right).skp
3D Model/Solar.skp
3D Model/SolarLid.skp

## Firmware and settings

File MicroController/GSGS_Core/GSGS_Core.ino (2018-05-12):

/* #############################
 * OSU:CS Senior Capstone 2018
 * Green Smart Gardening Project
 * Developed By:
 *    Brandon Ellis
 *    Jiayu Han
 *    Jack Neff
 * ############################## */


//Extra Comment Layout
/* ##############
 * 
 * ############## */
 
/* #############
 * Library Calls
 * ############# */
//Wifi Connection
#include <WiFi101.h>

//Allow Communication Via Pins
#include <Wire.h>
#include <SPI.h>

//Communication with BME180 Sensor
#include <Adafruit_BME280.h>
#include <Adafruit_Sensor.h>

//Scheduling System
#include <TaskScheduler.h>
#include <TaskSchedulerDeclarations.h>

//Header Files
#include "secrets.h"


/* ############################################################
 * Globals - BME
 *    These are used for making connections to the BME280
 *    At this point all connection methods are left in to 
 *      make swapping during development easier
 * 
 * //BME:
 * //Via I2C
 * // Adafruit_BME280 bme;
 * //Via SPI (Hardware)
 * // #define BME_CS 10
 * // Adafruit_BME280 bme(BME_CS);
 * //Via SPI (Software)
 * // #define BME_SCK 13
 * // #define BME_MISO 12
 * // #define BME_MOSI 11
 * // #define BME_CS 10
 * // Adafruit_BME280 bme(BME_CS, BME_MOSI, BME_MISO, BME_SCK);
 * 
 * //#define SEALEVELPRESSURE_HPA (1000.25) // need to change the relative HPA for acurate measuring
 *  used for altitude
 * ############################################################ */
Adafruit_BME280 bme; //I2C

/* ##########################################
 * Globals - Variables
 * 
 * HOUR   - 1 hour   = 2,600,000 milliseconds
 * MINUTE - 1 minute =    60,000 milliseconds
 * SECOND - 1 second =     1,000 milliseconds
 * ########################################## */
#define HOUR 2600000
#define MINUTE 60000
#define SECOND 1000


/* ######################################
 * Globals - WiFi
 * 
 * ssid - ssid to connect to,
 *    defined by secrets.h
 * pass - password for a specific network,
 *    if one is needed
 *    if not, will ommit in later call
 * status - WiFi's current status
 * 
 * connect_wifi() - Function Declaration
 * ####################################### */
char ssid[] = SECRET_SSID;
char pass[] = SECRET_PASS;
int status = WL_IDLE_STATUS;
void connect_wifi();

/* ################
 * Database Connect
 * ################ */
IPAddress server(35,227,147,235); 
WiFiClient client;

/* ###############################################
 * Scheduler Setup
 * 
 * Hardset Time Declaration
 *  Setting some defined times that can be swapped
 *    in.
 * Callback Method Prototyping
 *  Used for creating Tasks, will later be defined
 * Task Creation
 *  Initializing Task(to go every hour, forever,
 *    linked to the callback);
 * Scheduler Creation
 *  Initializing the Scheduler that will run everything
 * Callback Defining
 *  The work that the task will accomplish
 * ############################################### */
int five_sec = 5 * SECOND;
int five_min = 5 * MINUTE;
int day = HOUR * 24;

void core_callback();
void check_in_callback();

Task core_task(five_min, TASK_FOREVER, &core_callback);
Task check_in_task(day, TASK_FOREVER, &check_in_callback);

Scheduler runner;

void core_callback()
{
  //DEBUG INFO
  Serial.println("DEBUG: In core_task");
  Serial.print("DEBUG: Time to run in Millisecond - ");
  Serial.println(millis());

  //Iteration Checks
  if (core_task.isFirstIteration()) 
  {
    Serial.println("DEBUG: First Run");
  }

  //should never be true
  if (core_task.isLastIteration()) 
  {
    Serial.println("ERROR: core_task last run");
  }

  //CORE SECTION
  //connect to given Wifi network
  connect_wifi();

  //collect data, connect to database, send data
  post_data();

  //get scheduler time interval, end connection
  check_response();

  //close WiFi connection
  close_wifi();
  
  //Create whitespace to help differentiate
  Serial.println("");
}

void check_in_callback()
{
  //DEBUG INFO
  Serial.println("DEBUG: In check_in_task");
  Serial.print("DEBUG: Time to run in Millisecond - ");
  Serial.println(millis());

  //Iteration Checks
  if (check_in_task.isFirstIteration()) 
  {
    Serial.println("DEBUG: First Run");
  }

  //should never be true
  if (check_in_task.isLastIteration()) 
  {
    Serial.println("ERROR: check_in_task last run");
  }

  //CORE SECTION
  //connect to given Wifi network
  connect_wifi();

  //get scheduler time interval, end connection
  check_response();

  //close WiFi connection
  close_wifi();
  
  //Create whitespace to help differentiate
  Serial.println("");
}


/* ########################
 * Prep Code Section
 *  This runs once on start
 * ######################## */
void setup() 
{
  /* ################################
   * Serial Up
   *  begin Serial connection
   *  hold until the connection is up
   * ################################ */
  Serial.begin(9600);
  //while(!Serial) ;
  Serial.println("DEBUG: Serial Up");  
  
  /* ###############
   * Scheduler Setup
   *  .init - initialize the scheduler
   *  .addTask - add core task to scheduler
   *  delay - 5 seconds to get scheduler up
   *  .enable - start core task
   * ############### */
  runner.init();
  runner.addTask(core_task);
  runner.addTask(check_in_task);
  delay(5000);
  
  core_task.enable();
  Serial.println("DEBUG: Core Task Up");
  Serial.println("");

  check_in_task.enable();
  Serial.println("DEBUG: Check In Task Up");
  Serial.println("");

  /* #########
   * BME Setup
   * ######### */
   bool BME_status;
   BME_status = bme.begin();
   if (!BME_status) {
        Serial.println("ERROR: BME - Could not find a valid BME280 sensor");
        while (1);
   }
}

/* ##############
 * Loop = Main()
 * ############## */
void loop() 
{
  runner.execute();
}

/* ############################################
 * WiFi Connection
 *  while()
 *    prints ssid of attempted connection
 *    attempts connection
 *      pass:   status = WiFi.begin(ssid, pass)
 *      nopass: status = WiFi.begin(ssid)
 *    holds for connection
 *      5000 milliseconds = 5 seconds
 * ############################################ */
void connect_wifi() 
{
  if(WiFi.status() != WL_CONNECTED){
    Serial.println("DEBUG: In WiFi Connect");
    Serial.print("DEBUG: Wifi.Status: ");
    Serial.println(WiFi.status());
    
    while(WiFi.status() != WL_CONNECTED) {
      Serial.print("DEBUG: Attempting to connect to SSID: ");
      Serial.println(ssid);
      status = WiFi.begin(ssid, pass);     
      delay(10000);
    }
    Serial.println("DEBUG: Connected to Network");
    Serial.print("DEBUG: Wifi.Status: ");
    Serial.println(WiFi.status());
  } else {
    Serial.println("ERROR: Connecting to WiFi, already connected");
  }
}

/* ####################################
 * Closes the given WiFi Connection
 *  Considerably easier than connecting
 * #################################### */
void close_wifi()
{
  Serial.println("DEBUG: In WiFi Close");
    
  WiFi.end();
  
  Serial.println("DEBUG: Connection to Network Closed Gracefully");
  Serial.print("DEBUG: Wifi.Status: ");
  Serial.println(WiFi.status());
}


/* #################################################
 * Checks if the device is still connected to wifi
 *  ran each round of task
 *  if not connected, call connect_wifi and attempt,
 *    to connect
 * ################################################# */
void check_wifi()
{
  if(status != WL_CONNECTED)
  {
    Serial.println("ERROR: WiFi - Not Connected to WiFi");
    Serial.println("ERROR: WiFi - Attempting to Connect");
    connect_wifi();
  }
}

/* ############################################
 * Sends information to Database
 *  makes initial variables
 *  makes call to data build_data()
 *  connects to database and sends HTTP request
 * ############################################ */
 void post_data() 
 {
    //core string parts
    String send_start    = "GET ";
    String send_php_page = "/insert_data.php?";
    String send_data;
    String send_end      = " HTTP/1.1";
    String send_full;

    Serial.println("DEBUG: Posting Data");

    send_data = build_data();

    send_full = send_start + send_php_page + send_data + send_end;
    
    // If there's a successful connection, send
    if (client.connect(server, 80)) {
      Serial.println("DEBUG: Connected to Server");
      client.println(send_full);
      client.println("Host: 35.227.147.235");
      client.println("Connection: close");
      client.println();
      Serial.println("DEBUG: Finished Connection");
    } 
    else {
      //Connection failed
      Serial.println("ERROR: Connection Failed");
      client.stop();
    }
}


/* ############################################
 * Get scheduler time
 *  makes a request get scheduler time
 *  waits while it gets everything
 *    closes the connection
 *  requests update
 * ############################################ */
void check_response() 
{
  char reply_interval[10];
  int reply_size = 0;
  bool server_responding = false;
  //has server sent back '#'? This marks int start
  bool hit_marker = false;

  Serial.println("DEBUG: Checking Interval");
  
  // If there's a successful connection, request scheduler time
  if (client.connect(server, 80)) 
  {
    Serial.println("DEBUG: Connected to Server");
    client.println("GET /interval.php HTTP/1.1");
    client.println("Host: 35.227.147.235");
    client.println("Connection: close");
    client.println();
    Serial.println("DEBUG: Finished Connection");
    server_responding = true;
  } 
  else 
  {
    //Connection failed
    Serial.println("ERROR: Connection Failed");
    client.stop();
  }

  //if a connection was made, hold for the response
  while (server_responding)
  {    
    //if client is up and still communicating 
    while (client.available()) 
    {
      char c = client.read();

      //if special marker '#' is found
      if (hit_marker)
      {
        //Buffer overflow check
        if(reply_size > 9)
        {
          //Don't allow buffer overflow
        } else 
        {
          reply_interval[reply_size] = c;
          ++reply_size;
        }
      }

      //marker found, next info is interval
      if (c == '#')
      {
        hit_marker = true;
      }
    }

    // if server disconnected, close connection
    if (!client.connected())
    {
      Serial.println("DEBUG: Disconnecting from Server Gracefully");
      client.stop();
      server_responding = false;
    }
  }

  //validate and update new interval
  update_interval(reply_interval);
}

/* ############################################
 * Updates scheduler time
 *  checks to make sure that the reply is valid
 *  changes the scheduler time
 * ############################################ */
void update_interval(char *reply_interval) 
{
  int new_interval;
  
  //updating scheduler time
  new_interval = atoi(reply_interval);
  if (new_interval == 0)
  {
    //converted reply = 0
    //  could be caused by atoi error
    //  could have been requested, not possible for scheduler
    Serial.println("ERROR: Scheduler Time Returned = 0");
  } else
  {
    Serial.print("DEBUG: Valid Scheduler Interval | Time = ");
    Serial.print(new_interval);
    Serial.println(", Updating");

    core_task.setInterval(new_interval);
  }
}

/* ##################################
 * Builds data string to post
 *  makes calls to sensors
 *  builds data into string with keys
 *    keys defined by database
 * ################################## */
String build_data()
{
  //final string
  String ret_data;

  //database keys
  String key_temp = "temperature=";
  String key_humd = "humidity=";
  String key_pres = "pressure=";
  String key_mstr = "moisture=";
  String key_lite = "light=";
  String key_batt = "battery=";
  String key_ph   = "ph=";

  //string formatting
  String amp      = "&";

  //temp variables
  //  battery level
  //    not implemented yet
  int tmp_bat = 22;
  
  ret_data = key_temp + get_temp() + amp + key_humd + get_humidity() + amp + key_pres + get_pressure() + amp + key_mstr + get_moisture() + amp + key_lite + get_light() + amp + key_batt + tmp_bat;
  Serial.println("DEBUG: Returning Data");
  return ret_data;
}

/* ######################
 * Return BME Temperature
 * ###################### */
int get_temp()
{
  //debug version 
  int ret_temp = bme.readTemperature();
  Serial.print("DEBUG: Temperature Read - ");
  Serial.print(ret_temp);
  Serial.println(" Celsius");
  return ret_temp;
  
  //clean version
  //return bme.readTemperature();
}

/* ###################
 * Return BME Pressure
 * ################### */
int get_pressure()
{
  //debug version 
  int ret_pressure = bme.readPressure();
  Serial.print("DEBUG: Pressure Read - ");
  Serial.print(ret_pressure);
  Serial.println("hPa (Hectopascal)");
  return ret_pressure;
  
  //clean version
  //return bme.readPressure();
}

/* ####################
 * Returns BME Humidity
 * #################### */
int get_humidity()
{
  //debug version 
  int ret_humidity = bme.readHumidity();
  Serial.print("DEBUG: Humidity Read - ");
  Serial.print(ret_humidity);
  Serial.println("% Relative Humitity");
  return ret_humidity;
  
  //clean version
  //return bme.readHumidity();
}

/* ###########################
 * Returns Soil Moisture Level
 * ########################### */
int get_moisture()
{
  //debug version 
  int ret_moisture = analogRead(A1);
  Serial.print("DEBUG: Moisture Read - ");
  Serial.print(ret_moisture);
  Serial.println(" Relative Moisture Level");
  return ret_moisture;
  
  //clean version
  //return analogRead(A1);
}

/* ###################
 * Returns Light Level
 * ################### */
int get_light()
{
  //debug version
  int ret_light = analogRead(A2);
  Serial.print("DEBUG: Light Read - ");
  Serial.print(ret_light);
  Serial.println(" Lux");
  return ret_light;
  
  //clean version
  //return analogRead(A2);
}

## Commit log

2018-02-12 Began work on bringing our individual pieces of functionality together, globals and prep documentation (with the exception of wifi) are added. Currently working on Setup
2018-02-12 Adding work on GS2 core. Initial documentation & global setup (with exception of WiFi) is done. Currently working on Setup
2018-02-26 Added php code from dashboard alpha version. Careful with dummy_data_script, just loading that page will insert 50+ entries into database.
2018-03-15 Figured out issue with database connection, now works. Added call to both BME280 and Soil Moisture sensor. Changed call to WiFi setup to connect to WiFi only during scheduled run, instead of connecti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
    [GSGS_Core.ino]
2018-03-21 Last commit had an error. Adding function declaration to that, you know, functions know about each other.
    [GSGS_Core.ino]
2018-04-19 Refactored old code and made a correction to a bad status check
    [GSGS_Core.ino]
2018-05-07 Adds several things. Updates core code with two way communication and prevents buffer overflow. Adds automated test suite. Adds Spring Midterm Progress Report
    [GSGS_Core.ino, GSGS_Test_Suite.ino]
2018-05-11 Completed all functionality.
    Custom graph page is view_data.php, 2-way communication and parameter
    setting is parameters.php. Forecase formatting is not quite complete. I
    want to upload this full-functionality site now in case something goes
    wrong tomorrow.
2018-05-11 Adding second scheduler task, this checks in with the database every day. Improved readability of debug statements. Cleaned up unused code. Broke check in function into two, a check in and an interva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
    [GSGS_Core.ino, GSGS_Test_Suite.ino]
2018-05-12 3D model
    This is the 3D model files
    [MKR.skp, MKR.stl, MKRclip.skp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]
2018-05-12 Update
    Readme update
    [MKRclip.skp, MKRclip.stl]
2018-05-12 Found some bugs + added set number of reads on the homepage
    Fixed a broken button and added capability on homepage of settig the
    number of graphed data points
2018-05-18 Completely functional, ready for expo. Static weather forecast on this commit.
    Edited the following:
    Fixed dates on graphs
    Set search dropdowns to default to current date
    Number of reads now stays with the user if they change parameters on the
    homepage
    Reset button added to parameters page
    Graph lines no longer hug the top of the graph
